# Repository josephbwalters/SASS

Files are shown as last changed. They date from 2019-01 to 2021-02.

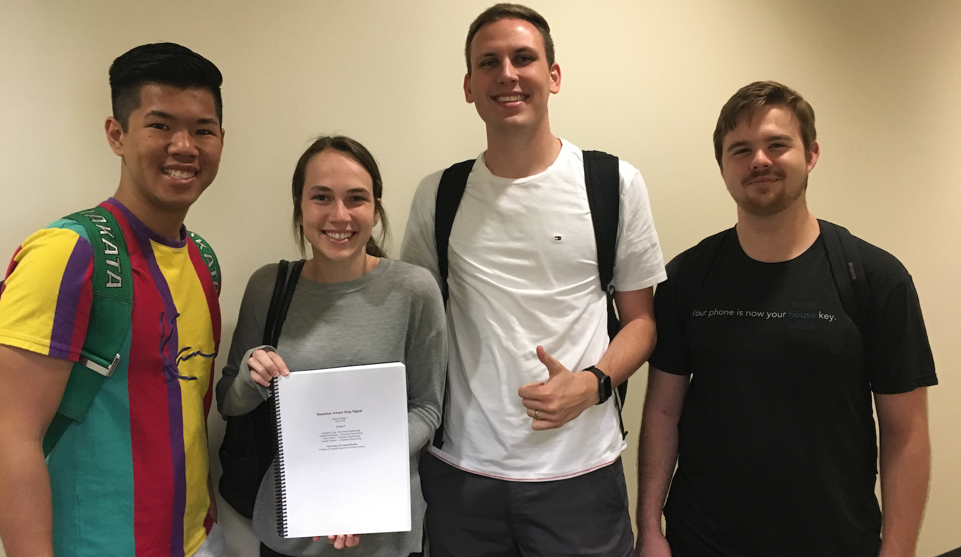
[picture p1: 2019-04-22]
docs/img/slider/SD1Paper_cropped.jpg

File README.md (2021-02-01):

# SASS
Repository for all code related to UCF CECS Senior Design Project (S.A.S.S. -- Fall 2018 - Spring 2019)

[SASS Github Pages](https://josephbwalters.github.io/SASS/) - Product overview and team details!  
[UCF SASS Website](https://www.ece.ucf.edu/seniordesign/fa2018sp2019/g03/) - it is a copy of our overview site  
[All UCF Projects](https://www.ece.ucf.edu/seniordesign/projects.php) - all UCF senior design projects  

## Installation:
- Clone Repo
- Open SASS, MSS, and DSS seperately in Code Composer Studio (CCS)

## Building Software
### SASS
- Build using CCS

### MMWAVE
- Build DSS in CCS
- Then build MSS in CCS

## Flashing Firmware onto devices
*Note: This is done after building each component*
### SASS
- Using CCS and a MSP432P401R EVM (Dev. Kit) you can flash the system externally

### MMWAVE
- Take the mmwave .bin file from the MSS' Debug folder and use UniFlash to flash the mmwave EVM

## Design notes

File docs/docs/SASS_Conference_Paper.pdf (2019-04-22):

# Situation-Aware Stop Signal

Jon Ling, Annabelle Phinney, Trent Sellers,

### Joseph Walters

Dept. of Electrical and Computer Engineering, University of Central Florida, Orlando, Florida, 32816-2362

Abstract — Advancements in technology made in the last two decades have made possible the rethinking and redefinition of traffic control at small intersections. Using new and more affordable LiDAR and RADAR technology, the Situation-Aware Stop Signal is aimed to reduce the number of accidents that occur on the smaller roads of our communities and, ultimately, save lives. A sustainable, solar-powered design allows the stop signal to be deployed and maintained for a low cost while eliminating its need for area utilities.
Index Terms — Embedded software, microcontrollers, millimeter wave radar, road transportation, solar energy, sustainable development, traffic control.
I. INTRODUCTION

At the crossroads of one small neighborhood in Orlando lies a small memorial at the corner of a four-way stop. It stands in remembrance of someone’s loved one – a neighbor – who lost their life in a fatal accident in that very same place. Every year, in our community and in others, there are a multitude of accidents that occur at small, residential intersections controlled by stop signs. A 2002 study by the Insurance Institute for Highway Safety found that one third of all intersection crashes in the United States, and over 40% of those fatal, took place at intersections where these were the primary traffic control device [1]. Accidents of this kind are often the result of drivers running stop signs due to visual distraction, the influence of alcohol, and other forms of carelessness. Stop signs have long been important tools for controlling traffic at small intersections, but they are becoming less effective in an age when both traffic and distractions are more present than ever on the road.
Since the first stop sign was installed in Detroit in the year 1915, the approach for managing traffic at small intersections has not changed by a great amount. The need for change, however, has never been greater. Living in an age dominated by small, bright screens and various forms of handheld or otherwise easily-accessible entertainment, there is more potential for accidents to occur today than in any other time in history. These new distractions introduce complex issues into the realm of roadway safety and pose a serious threat to drivers if not mitigated.
A concern for the safety of others, paired with an admiration of current technology, has led us to rethink traffic control at the enforced stops of our community. The culmination of this thought is the Situation-Aware Stop Signal. Where conventional stop signs are insufficient, the Situation-Aware Stop Signal is intended to draw greater attention to the roadway and be a catalyst for safer crossings at small intersections. Influenced by technology found in existing traffic lights and autonomous cars, this intelligent system is designed to be a modern and more effective replacement for the stop sign. Using advanced sensors and real-time computing, the Situation-Aware Stop Signal is able to monitor the intersection for traffic and provide intuitive warnings to drivers.

II. OBJECTIVES

A. Prevention of Threat

A threat exists when a driver does not slow down as he or she approaches the intersection. This may be due to some form of a distraction, such as the use of smartphones while driving, or could be the result of driving under the influence of alcohol or other impairing drugs. For this situation, the stop signal was designed to alert the driver to slow down and to come to a complete and safe stop.
By triggering the driver’s senses, particularly sight, the stop signal is able to help him or her maintain his or her eyes on the road ahead. Implementing this required a need to understand human psychology and the behavior people tend to exhibit while driving. Throughout our study, we observed that people seem to respect traffic lights more than stop signs. This observation was fundamental in exploring our method of redirecting the driver’s attention.
To capture attention and prevent a driver from driving through the intersection, the stop signal indeed acts similar to existing traffic lights. Until a vehicle comes to complete stop, the signal provides a solid red light as an indicator that the driver must stop. This was decided due to people’s familiarity with the stops of larger traffic control systems and their association of these with the consequences of violating such stops. When a vehicle has remained stationary for a period of time at the stop bar, the signal gives a flashing yellow light to indicate that the driver may proceed with caution. It was decided against using a green light to 1) invite the driver to be aware of other vehicles even while crossing and 2) provide a distinguishable experience from that of larger traffic control systems.
B. Protection from Threat
v = $2 ∗ range ∗ μ ∗ g | (1)

Should a driver constitute a threat and not slow down as he or she is entering the intersection, it is of critical importance to alert all other drivers at the intersection and keep them immobilized until the threat has passed. In such a situation, the traffic control system must attempt to keep everyone safe. This situation is given the highest priority amongst all other situations that may occur at the intersection.
A threat must be detected and classified well before it reaches the intersection. Here, a study of car velocity, driver reaction time, and safe stopping distance was required to properly identify danger. These factors were considered in the interpretation of sensor data and the primary function of the algorithms that were written in the project software. This ability to process data was directly dependent on the speed at which it could be captured. This second consideration, a need for real-time situational awareness, was the principal consideration of the embedded software design.
The Situation-Aware Stop Signal uses mmWave RADAR to track vehicles as they approach the intersection. As RADAR tracks a vehicle, it continuously compares its speed to that which it considers safe given its distance from the intersection. This analysis is represented in (1). Once RADAR detects a threat, the system immediately enters an emergency mode. In this mode, all lights are turned red, preventing any other vehicles stopped at or approaching the intersection from crossing. The stop signal continuously checks all sides until no threat remains. Once the intersection is determined to be safe, the signal exits the emergency mode and resumes normal operation.
C. Scheduling of Traffic

Oftentimes, drivers stop at the intersection at the same time and do not proceed for concern of incorrectly assuming or yielding the right of way. When this occurs, not only is traffic flow constrained, but a new threat to safety may be presented. By implementing basic scheduling with the stop signal, we took an opportunity to correct this issue.
We acknowledged current traffic laws and designed our system to direct traffic in a manner that is consistent with the behavior they dictate. We aimed to recognize all combinations of driver presence at the intersection and understand the order by which traffic should proceed in every unique case. A study of driver behavior and arrival times at small intersections was necessary to sufficiently consider timing when scheduling traffic. Although this was likely to vary greatly between drivers and locations, an average or more probable pattern of traffic flow and management was defined.
To implement fair scheduling of vehicles at the intersection, we designed the stop signal to operate using a simple FIFO queue. Simply put, the first vehicle to arrive is the first vehicle to be scheduled. The management of this queue performed by software running on a 48MHz processor allows the stop signal to capture vehicles when they arrive – whether they be hours, minutes, seconds, or microseconds apart. Current traffic laws indicate that should two vehicles arrive at the same, the one on the left should yield to the one on the right. With the Situation-Aware Stop Signal, virtually no vehicles are found to arrive at the very same time. There is always a “winner”: the one who is found to arrive first.

III. SELF-SUSTAINABILITY

The Situation-Aware Stop Signal was designed to be self-sustaining. Although its manufacturing cost was acknowledged to be greater than conventional stop signs, it was determined that it should not imply a significant operational cost. Current traffic control systems at larger intersections require connections to area utilities and are either dependent on existing infrastructure or demand its extension. Such investment and continuing operational costs can lead to a great expense for the governments or private industries that manage them. Contrarily, the stop signal was created to reduce these costs and be deployable in diverse locations where area utilities may not reach.
To be independent of local power grids, the stop signal operates on solar power. A 28-inch by 28-inch solar panel rests overhead of the main control box and generates over 80W of power using 25 solar cells at 0.6V at 6A each. These solar cells were produced by Sunpower, which are currently the industry leader for consumer level solar cell production. These cells are a monocrystalline design which means that it is pure slices of silicon rather than melting smaller pieces of silicon into a single cell. Because these cells have less imperfections than its competitors, it allows them to be more efficient.
A solar charge controller manages power generated by the solar panel and regulates its storage in an on-board 12V lithium ion battery. While the solar panel is producing more than the device’s operating voltage, the charge controller will regulate the voltage going into the device to the desired 12V. To optimize the storage of the power generated via the solar panel, a MPPT (maximum power point tracking)

charge controller was used. The MPPT charge controller similar technology as PWM (pulse width modulation) charge controller; however, these charger controllers can retain more of the generated power. With other PWM charge controllers as well as single stage charge controllers, excess voltage will be lost upon supply to the battery. With an MPPT charge controller, excess voltage can be converted into additional current. Using MPPT charge controllers will allow for larger solar panels which may be to maximize usable solar panel space.
By providing over 80 watts to our battery while only consuming about 12, our device stays low power. The additional power consumed during sunshine hours will be used to charge the battery. Florida produces about six solar hours a day, so the solar panel needed to produce at least four times the devices demand to say sustainable. This would account for the continuous operation of running 24 hours in a day. The battery that was chosen for this project has a capacity of 20Ah. Given our design operates at under 1A draw, our device will be able to operate for a day without any sunlight hours. Having the battery backup allows for days that have small amount of sun hours.

IV. MODULARITY

Modularity is vital to provide easy means of adjusting the signal to meet the needs of any intersection. While the goal of this project was to design a signal intended to replace stop signs at smaller intersections, the product was designed modularly with the ability to be expanded to larger roadways and eventually be used to replace traffic lights. Modularity appears throughout the device; where there is hardware modularity, there is also software modularity that conveys the design’s robustness.
The physical design is where most of the modularity is seen. The use of 3D printed mounting brackets for both the RADAR and LiDAR sensors, allows the user to adjust the angle of the sensor to meet the needs of any intersection.** Additionally, with so many different types of intersections out there, the addition of removable side modules allows the user to add to take off any of the sides to suit the intersection more accurately. While our design only has two side modules on currently, more modules can easily be added in the future thanks to the use of the connectors on the back of the center module. As mentioned previously, testing the device with ease was another aspect in our design. Accessing the hardware inside each module was necessary to debug and ensure that all the components of the design were working together correctly. This was achieved by adding sliding hinges to the modules. This allows the owner to see the inside of the module and spot issues more easily. These additions to the physical design improved the quality of testing and highlight the easily adjustable nature of this unique stop signal.
Modularity also exists in the software. With the ability to add or remove more sides to the signal, comes the ability to adjust the software to the size of the current intersection. With just a simple numerical entry of the number of required sides, the software can detect cars from as many sides as the user requires and pull from the appropriate number of sensors. This can help improve efficiency and save power. If some users only require one modular side, the sensors in the remaining sides will be off and not be collecting unnecessary data, thus improving efficiency. Additionally, an ample amount of power is saved by not turning on extra lights and sensors.
Power is the final aspect of the modularity in this design. Because a requirement of this device was self-sustainability, the main source of power for this project is the solar panel. While this may provide the required amount of power, the majority of the time, when there is little to no natural sunlight, the device still needs to be functional. To achieve this, the addition of the battery introduces an additional power source for the device. While the sun is out, the device can be directly powered from the solar panel, however, on a cloudy day, the power gathered from the panel which is stored in the battery can be used to keep the signal functional. This second power source creates additional modularity for the system to ensure this device will be constantly operational.

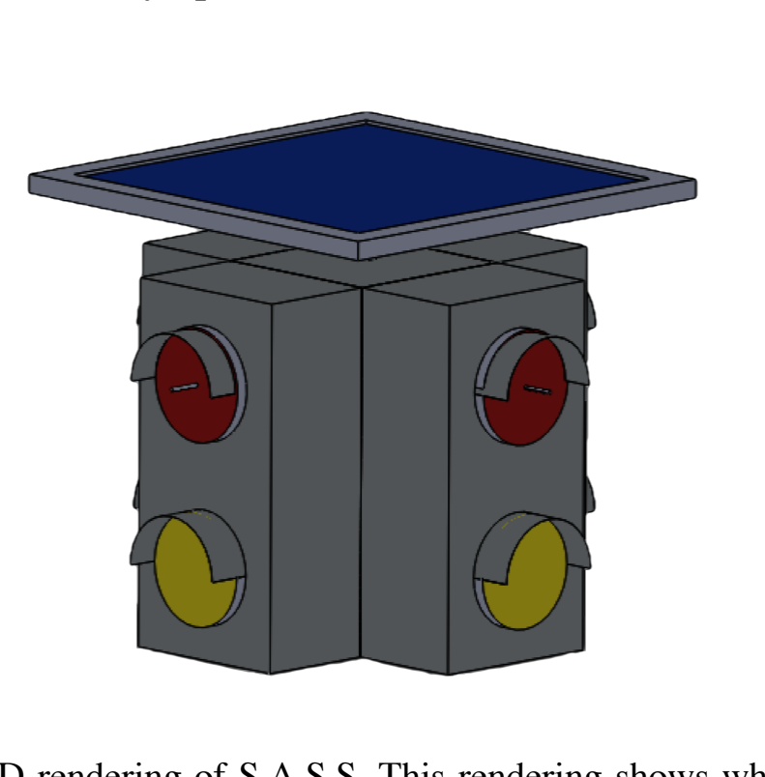
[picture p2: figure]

Fig. 1. 3D rendering of S.A.S.S. This rendering shows what the device would look like if implemented for a 4-way intersection.

V. STANDARDS
The design goal of this device was to mimic the look of a current stoplight that is seen on an everyday intersection. For this reason, we closely followed the Manual for Uniform Traffic Control Devices. All box dimensions, light sizes, and height have been in accordance with the Department of Transportation’s standards.
Indicated in Figure 4D-4 in the Manual for Uniform Traffic Control Devices, the standard for the 12-inch lights presents a maximum of 180 feet from stop line to signal face. The standard for 8-inch signal indications is 120 feet from signal face to stop line.
The Manual on Uniform Traffic Control Devices states that traffic signals should determine who has the right of way by using priority control. Priority control is used by the signal to select the driver with the right of way by allowing whichever driver who stopped at the intersection first, to proceed through the signal first.
In addition to the traffic standards that were followed when creating this project, there were many hardware standards and testing standards that allowed the project to be completed correctly. While we are only dealing with low power electronics, it is still vital that the power supply and delivery standards be followed correctly. These efficiency standards for power supplies provide tests for the worstcase scenario of the circuit and require certain minimum and maximum power outputs in any scenario.

VI. HARDWARE
The one major focus of the hardware design was to save power. This engineering requirement played an important role in both choosing hardware, such as sensors as well as how designing the PCB. Another goal of the hardware was to create redundancy and ensure the safety of all drivers. To achieve this, two different types of sensors were included in the stop signal: RADAR and LiDAR. These sensors, along with the PCB makeup the hardware electronics. The PCB was able to be designed without a maximum size requirement while keeping in mind an efficient output. Because this system will operate in real time and need to rapidly control lights, minimizing unnecessary components and trace lengths helped improve the functionality. Additionally, because the device will be operating outside, eliminating excess heat was achieved by swapping out a large linear regulator with a switching regulator. While the linear regulator helps eliminate noise, it loses a lot of power through heat dissipation. Because this board does not contain any major high frequency elements, saving power was more important than eliminating noise, which is why the switching regulator was used for the 12V to 5V step down. While power efficiency was a large concern, testing was another one. As a result, the PCB was designed with testing in mind. Signal LEDs and test pins were incorporated throughout the PCB to ensure that the regulators and other major components could easily be tested. This helped to easily identify and correct any major issues with the PCB.

At the heart of the PCB is the TI MSP432P401R microcontroller. Not only do we need a design that is power efficient, we need a design that can also perform adequately to read and interpret sensor data provided by the RADAR and LiDAR modules. This processor was chosen due to its extra memory, large number of GPIO pins, and compatibility with RTOS. This MCU also provided a quick and efficient means of flashing code, testing, and debugging the software. Because the MSP432P401R evaluation board was provided to us by the TI lab for testing the MCU, we were able to also use this evaluation board to flash our board with the designed software. This made testing both easy and efficient.
Accuracy was another major requirement of this project. In order to monitor and control traffic, creating redundancy allowed for us to ensure the safety of drivers who cross the intersection. This redundancy was achieved by sensor fusion or the use of both RADAR and LiDAR sensors to detect oncoming traffic. While the LiDAR and RADAR are being used in different ways to detect traffic, together they will provide more accurate readings of the way that traffic is behaving.
The RADAR module chosen uses mmWave sensors to detect objects with a frequency of over 100 GHz, the smaller wave size provides a more accurate and speedy result when detecting objects. This module includes an evaluation board that helps process the data gathered from the RADAR. As a result, this module will be placed inside the signal. The focus of the RADAR board is to gather the position and velocity of all oncoming cars. It will also detect and alert our PCB of any potential threats to the intersection.
Like the RADAR, the LiDAR is a time of flight sensor that uses a laser to detect objects within a thin beam width. While the LiDAR does not include an evaluation module, it includes a durable weather resistant casing, which allows the sensor to be placed outside the module. The main job of this LiDAR module is to initially detect any car approaching the signal. This sensor will be alerting the PCB if an object is detected and stopped at the stop signal. Then, unless a threat is detected by the RADAR, the LiDAR will alert the PCB that there is an object and, after the appropriate amount of time, allow that car to proceed through the intersection safely. The use of two different types of sensors that cover different ranges allows for more data and the redundancy required to provide a safe means of controlling traffic.
In addition to the hardware electronics, comes the power hardware. In order to make our device both power and cost efficient, a solar panel was chosen to be the main source of power for this device. This decision was made not only to save the user the cost of tying this device to the power grid, but also to increase ease of installation. While some components of this device are relatively more expensive than the traffic lights, the total cost saved from using solar power versus grid power makes up for the more expensive sensors used in the project. Also, the use of the solar panel can reduce the installation time drastically and allow this device can placed nearly anywhere, regardless of whether there are power lines near or not.
Because the solar panel was designed and created by us, we were able to focus on purchasing the most efficient solar cells possible to improve the overall power gathered from the panel. For example, since monocrystalline solar cells can generally produce more power than polycrystalline cells, these were chosen for the solar panel. While these cells were a bit more costly, it was worth the additional power gained to use them. Also, building a solar panel allowed for additional savings.
While the solar panel provides a lot of power, there is still a need to power the device in overcast or cloudy conditions. To do this successfully, a battery was chosen as an additional power source to allow the device to still work when there is not enough sunlight to power the solar panel. The battery chosen to do the job was the GTK 3S Lithium Ion battery. These batteries store more power and charge faster than lead acid batteries. The battery chosen was also much lighter than alternatives. This helped lower the overall weight of the traffic signal.
To ensure reliability and efficiency of the design, an MPPT charge controller was added to supply a constant voltage from the battery even while to device is charging. We decided to use an MPPT style charge controller over a PWM charge controller. MPPT charge controllers offer efficiencies over 95%, and the one we decided on has a max efficiency of 98%. By utilizing a charge controller, the lifespan of the battery can be improved. Charge controllers improve the lifespan of the battery by trickle charging after the battery is nearing maximum capacity as well as providing protection against overcharging. The charge controller will be placed between the battery, solar panel, and PCB. For our application, our solar panel will produce 15 volts during operation. Our charge controller is rated to be able to step this down to 12 volts during operation which is a key feature of this device. The charge controller also includes a display that will show the status of both the battery and charge controller. With the addition of the charge controller, the voltage that the PCB receives can now be limited and regulated to a near constant value.

VII. SOFTWARE

The software of the system is broken down into four components which are:

1) Low-Level Hardware Abstraction
2) Object Detection
3) Object Classification
4) Traffic and Light Control

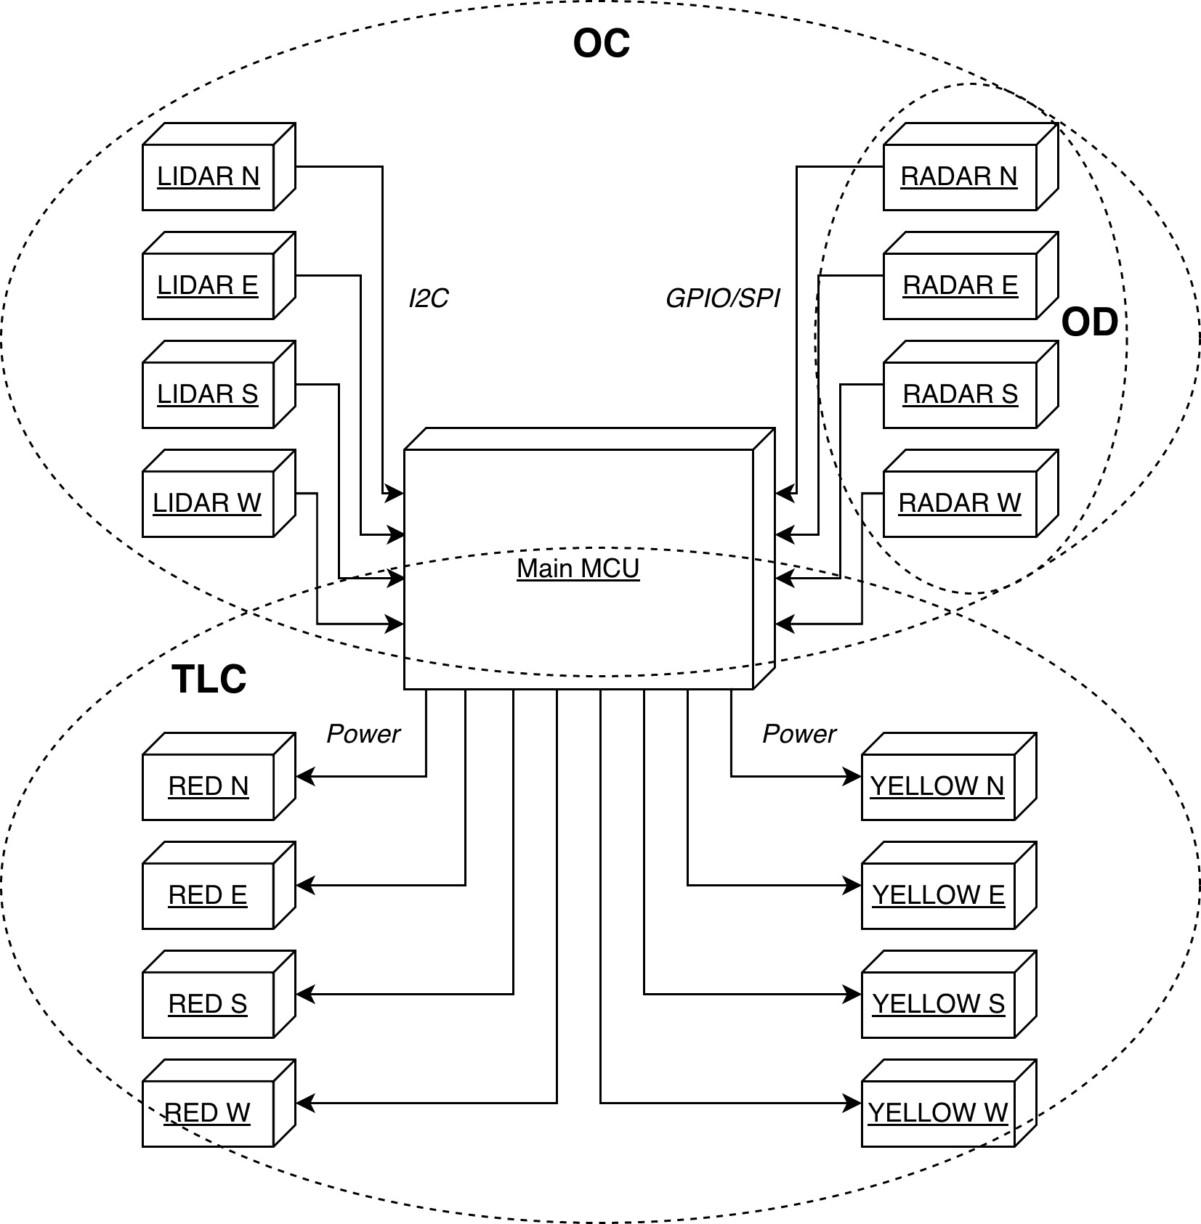
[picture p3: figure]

Fig. 2. Deployment diagram depicting three of the four software components used in the Situation-Aware Stop Signal: Object Detection (OD), Object Classification (OC), and Traffic and Light Control (TLC).
A. Low-Level Hardware Abstraction (LLHA)

The LLHA component is responsible for abstracting out the hardware that we used to prototype the design. Since we want this system to be modular and adaptable, it was essential that we design a common API-based system to perform all of the hardware-based functionality of our system. Doing this also simplified the design of the higherlevel logic that we were to use in the rest of the system. Currently, the LLHA component controls the lower-level settings for the LED lights, the I2C communication for the LiDAR, and the SPI communication for the mmWave device. This is done so that we can abstract out the hardware required for each side of the device in a modular way. The device could theoretically have 4 sides, so the software is designed to accommodate those sides through the settings within the LLHA submodule.

B. Object Detection (OD)

The OD component is responsible for detecting objects that the system can then respond to. This module relies on both the mmWave RADAR sensor and the LIDAR-Lite v3HP LiDAR sensor to detect vehicles that are entering the intersection. Object detection mainly takes place on the mmWave device since it is more capable of sensing vehicles that are moving towards the intersection. Then, once the vehicles are approaching the stop bar, the LiDAR device takes over and provides added information as to when the vehicle stops at its specified location.

C. Object Classification (OC)

The OC component isresponsible for determining if each oncoming vehicle is considered safe or unsafe based on (1). Similar to the OD module, OC is started on the mmWave device which monitors the oncoming vehicle to constantly check if the vehicle is safe or not. Once a vehicle is determined unsafe, the mmWave device then triggers a hardware interrupt that will then force the system into emergency mode.
Alternatively, if the vehicle is determined to be safe then the system will operate normally, resulting in the device monitoring the LiDAR sensor for a vehicle that stops at the specified location for that side of the intersection.
Once the vehicle is in the proper location, the OC module is responsible for verifying that the vehicle is also still located in the intersection at that location. After validating that information, then the OC sends the vehicle object to the queue managed by the TLC submodule.

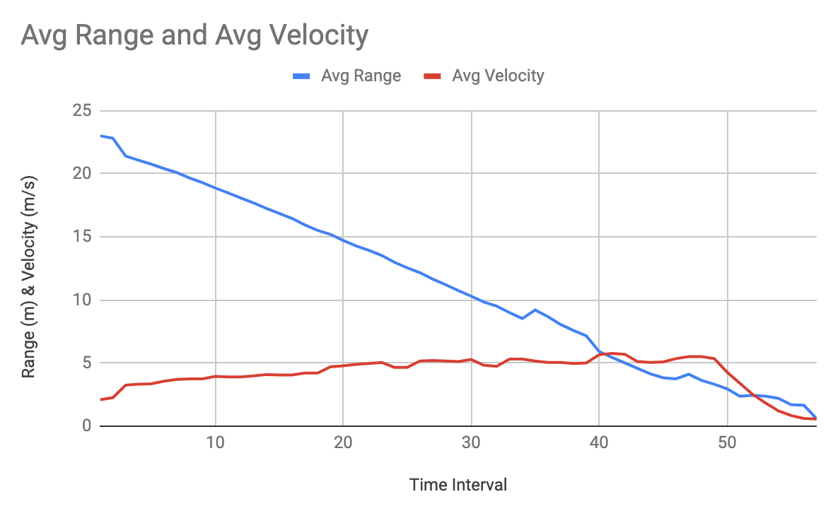
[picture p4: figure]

Fig. 3. Noise-reduced model of time vs range and velocity data gathered by the mmWave RADAR sensor (from captured logs).
D. Traffic and Light Control (TLC)

The TLC component is responsible for monitoring the state of the device and scheduling vehicles as they arrive in the intersection. This is achieved by inserting a new vehicle object into a queue. Doing this allows us to monitor each vehicle that arrives in the intersection while also keeping track of which side the vehicle has approached from. By doing this, we allow the TLC submodule to understand the state of the entire system, without knowing the implementation of the rest of the system. This is perfect for a traffic control device like this as it allows the scheduling mechanism to be updated and changed independently of the rest of the system and could then be optimized to allow for higher throughput.
The TLC is the perceived heart of the system as it is the only module that directly affects the external world. If the TLC does not work, then the entire system is a failure since it is the management system for all of the lights and traffic control. Currently, the TLC and the rest of our system abide by all of the standards and regulations defined in the Manual on Uniform Traffic Control Devices (MUTCD) and, accordingly, the system has a failsafe mode so that the system can deal with software and hardware failures as necessary.
E. Emergency Mode

As briefly noted, on detection of an unsafe vehicle, we trigger a hardware interrupt to force the system into an emergency state. We decided to use an interrupt-based approach because this would ensure that our system responds to the thread regardless of the thread that is currently running.
While in emergency mode, we rely on the mmWave sensor on each side to report back through the GPIO pin the status of the vehicles that are in view. While checking the status of each vehicle, we keep all lights on the system set to red to indicate that no vehicle is allowed to enter the intersection as there is a possible threat. Based on our implementation, as long as there is a vehicle that is detected that is considered a threat, the system will stay in this mode.
F. Failure Mode

Since drivers rely on traffic control devices to determine their actions when driving, it is important to ensure that our system is reliable and safe. Because of this, we included a default error-catching utility using a software interrupt that forces the system into a permanent failure state until the system is reset. In this mode, the system follows common traffic laws outlined in the Manual on Uniform Traffic Control Devices and the system will blink red approximately sixty times per minute to ensure that operation of the intersection defaults to that of a typical 4-way stop. Errors that could cause this are deadline failures, LiDAR sensor failures, and control failures. This ultimately gives the system a reliable way to fail without causing any sort of accident.
Since the software interrupt handles the LiDAR sensor failures, we still need another way to handle the mmWave sensor failures in case that sensor fails. If the sensor were to fail, it would never trigger that interrupt and in this case, that results in normal operation for the device, without the emergency detection feature.
For a more robust approach, this interrupt driven approach could be adapted to include more features such as self-reset and/or external LTE communication out to let a central control center know that the system is down. For us this was not within scope of the project in the time frame that we have, but it would be something that is important for a real production level system that is within the intersection.
G. Real-Time Operation using TI-RTOS

It was determined early on in the design of the Situation-Aware Stop Signal that the system should operate quickly, reliably, and deterministically due to its safety-critical nature. For this reason, it was decided that the software should be managed by a real-time operating system (RTOS). TI-RTOS, Texas Instruments’ own RTOS product, was selected as the operating system to power the stop signal software because of its open-source nature and extensive support for both the MSP432 microcontroller and C++ programming language.
Multithreading support in TI-RTOS allows the stop signal software to run multiple threads of execution. Because the MSP432 microcontroller has one core, these threads are scheduled so execution time is shared in a fair and deterministic manner. The Situation-Aware Stop Signal software makes use of priority scheduling and three unique types of threads provided by TI-RTOS: tasks, software interrupts (SWI), and hardware interrupts (HWI). SWI inherently have greater priority than tasks, and HWI greater priority than SWI. Tasks are used for code pertaining to regular, safe operation. SWI are used to trigger system failure should any hardware or software issues exist. HWI are used to trigger the emergency mode when a threat is detected, exhibiting the highest priority to ensure the safety of drivers at the intersection.

VIII. FUTURE USE

Currently, the Situation-Aware Stop Signal is designed for an intersection with stop signs, but that does not mean that this technology or our methods are not adaptable to more complex intersections. With RADAR and LiDAR technologies becoming more affordable within the last decade and advancements in low-power computer visionbased systems, it is much more likely that traffic systems will start being updated to do exactly what we have done with small intersections.
Computer vision is typically expensive and powerhungry but with new systems like the Nvidia Jetson and mmWave Radar sensor it is possible to replace the timerand induction-based systems with RADAR, LiDAR, and computer vision systems. Doing this is currently not costefficient, but over the next few years it could be within reach to start replacing those systems to include smarter technologies to detect threats, increase throughput, decrease waiting time, and catch criminals.
One additional and needed feature for updated systems like S.A.S.S. would be an ability to catch and ticket drivers for not abiding by the laws of the road. This is because this is a large source of income for the states. Many systems do this already, but this would enhance that functionality and also bring it to smaller intersections that are more likely to have accidents.
Another possible use case for systems like this is exactly the use case that we addressed with S.A.S.S. We currently solved the problem for small intersections, but with more time, money, and equipment it is completely possible to increase the efficiency of the software and to enhance its functionality by allowing the system to monitor larger areas and accommodate different types of detected objects such as pedestrians, bicyclists, and animals. Doing this would allow a traffic management system to monitor the safety of drivers and pedestrians in a proper manner and could easily prevent accidents in high-traffic, inner-city roads.
With that in place, it is also possible to increase throughput of all vehicle and pedestrian traffic by allowing the system to control each component of the system and determine the optimum timings to allow for maximum throughput using machine learning. Some systems already do this using computer vision and sensors within the roadways, but this could give a more robust solution that relies less on sensors embedded in roadways.
While the device is already somewhat modular, in the future, even more modularity could be incorporated in the signal. While the device can detect bicyclists, a crosswalk or pedestrian crossing is very common in most intersections. The ability to detect pedestrians and alert the drivers by turning all the lights red could improve upon the goal of saving people’s lives. While we originally wanted to be able to mount the solar panel on top of the device and have the ability to be rotated depending on the sunlight. A rotating solar panel would increase the amount of sunlight the solar panel could use and, as a result, provide more power to the device in a shorter time. With more money, resources, and time, a movable solar panel bracket could greatly improve the self-sustainability aspect of this device. Also, because the device itself required more power than originally expected, in the future, a larger battery with more capacity would be used to reach the goal of being selfsustainable for two days without sunlight. Because there is still a lot more space in the device, a larger battery would not affect the physical design.

IX. CONCLUSION

The Situation-Aware Stop Signal demonstrates the effectiveness of modern technology working in concurrence with outdated traffic units. While following MUTCD traffic laws, this device built upon current traffic control units which relied on timed algorithms. Using LiDAR and RADAR sensors, this device is able to detect where cars are within an intersection and use this data to more safely and effectively control traffic.
A major requirement of the Situation-Aware Stop Signal is to keep drivers safe and prevent car accidents. With this in mind, the design challenge became how to orient this device so that it does not distract or confuse drivers. The solution to this challenge was to design the device so it resembled a traffic light, the difference being that our device does not have a green light. This decision was made as a result of our implementation directed towards smaller intersections. Rather than giving the drivers the “go” signal, this device tells drivers to “proceed with caution.” Proceed with caution better fit the scenario for the traffic device which was being replaced.
While the idea is expandable to larger intersections, the goal of this project was to focus on smaller intersections that currently have stop signs. Technology such as robust as RADAR and LiDAR are scalable to larger applications. Applying this idea to larger areas could reduce the amount of traffic incidents, increase the flow of traffic in dynamically changing traffic patterns, and provide lower cost traffic control to modern, adapting areas.
Ultimately, the Situation-Aware Stop Signal will be selfsufficient and able to easily be integrated into society because of its stop-light-like appearance. We hope this project improves traffic on low volume roads while reducing both traffic accidents and waiting time for cars. This idea opens up further opportunities to expand and build upon the idea of a smart, intuitive traffic signal.

ACKNOWLEDGEMENT

The authors would like to acknowledge Texas Instruments for providing them with two of their latest IWR1642 mmWave RADAR sensor evaluation modules, two MSP432P401R evaluation modules, and various samples for other processors, regulators, and other minor components for free. They thank Don Harper and the staff of the TI Lab for allowing them to use their equipment to fabricate the physical components of our device.
They also want to express their appreciation for the mentoring, support, and feedback of Professor Michael

McAlpin during the development of the Situation-Aware Stop Signal.
Finally, the authors wish to acknowledge the families of those individuals who have lost their lives in motor vehicle accidents at small intersections and at all crossroads of their communities.

AUTHORS

Jon Ling is an electrical engineer from Merritt Island, Florida. Jon worked primarily on the power system, mechanical design, and PCB of the Situation-Aware Stop Signal, focusing on the distribution of power from the solar panel and battery source to all electrical components in the system.

Annabelle Phinney is an electrical engineer from Jupiter, Florida. Annabelle worked primarily on designing the PCB of the Situation-Aware Stop Signal, architecting much of the printed-circuit design while researching and acquiring the necessary electrical components.

Trent Sellers is a computer engineer from Orlando, Florida. Trent worked primarily on the embedded software of the Situation-Aware Stop Signal, focusing on the programming of the PCB
with | a | particular | emphasis | on
multithreading | and | real-time
applications.

Joseph Walters is a computer engineer from Orlando, Florida. Joseph worked primarily on the embedded software of the Situation-Aware Stop Signal, focusing on the programming of the TI mmWave RADAR module with a particular emphasis on algorithm development and communications.

REFERENCES

[1] “Drivers Often Stop but Don't See.” IIHS, 2002, www.iihs.org/iihs/sr/statusreport/article/37/9

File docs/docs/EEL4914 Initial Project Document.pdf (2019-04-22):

Initial Project Document

## Situation-Aware Stop Signal

Senior Design 1

Group 3

Jon Ling - Electrical Engineering Annabelle Phinney - Electrical Engineering Trent Sellers - Computer Engineering Joseph Walters - Computer Engineering

University of Central Florida College of Engineering and Computer Science

Group 3
EEL 4914
09/27/2018

Project Narrative

At the crossroads of one small neighborhood in Orlando lies a small memorial at the corner of a four-way stop. It stands in remembrance of someone’s loved one – a neighbor – who lost their life in a fatal accident in that very same place. Every year, in our community and in others, there are a multitude of accidents that occur at small, residential intersections. These are often the result of drivers running stop signs due to visual distraction, the influence of alcohol, and other forms of carelessness. Stop signs have long been important tools for controlling traffic at small intersections, but they are becoming less effective in an age when both traffic and distractions are more present than ever on the road.

Our goal is to design a system that has the potential to change our community – that is, to improve driver safety and save lives. We propose a replacement to the conventional “stop sign.” We propose a Situation-Aware Stop Signal.

The Situation-Aware Stop Signal, influenced by technology used in existing traffic lights and autonomous cars, is designed to be modular and implementable at small intersections currently guarded by stop signs. Using object-detecting technology like RADAR and LIDAR, the Situation-Aware Stop Signal is capable of detecting approaching vehicles and intelligently alerting drivers. Situational awareness made possible by its strategic placement allows the Situation-Aware Stop Signal to anticipate safety-critical events before they occur.

This ability is conducive to a two-part mission for the project:

1. To help drivers stop safely before the intersection
2. To protect drivers from others who may not be stopping safely at the intersection

To help a driver stop safely before the intersection, a traffic signal is displayed to alert the driver that he or she is nearing the intersection and needs to stop. To protect a driver from others who may not be stopping safely at the intersection, the driver is given a visual alert if cross traffic is detected as coming from either perpendicular direction. This is particularly useful for intersections that are populated with trees and other objects that may obstruct the driver’s vision when preparing to cross the roadway.

09/27/2018

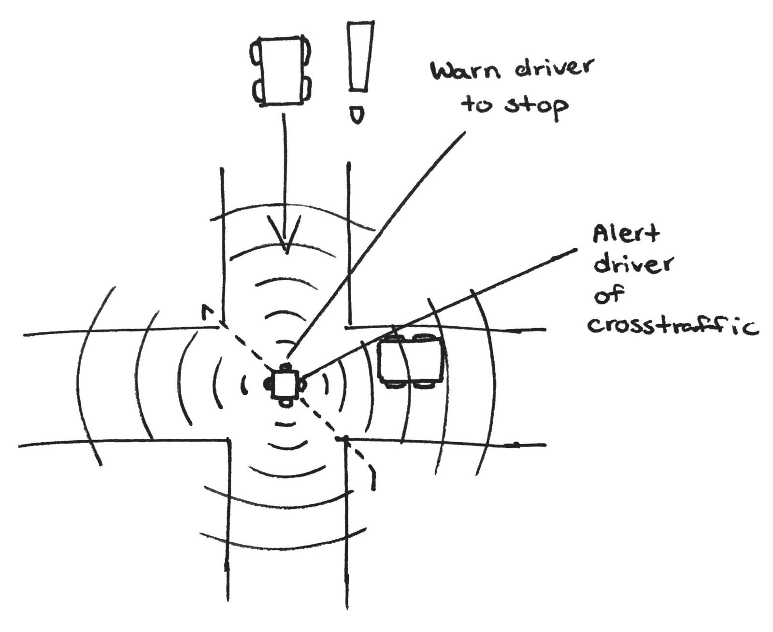
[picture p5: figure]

Figure 1: Sketch of idea

In order to achieve this ambitious mission, it is necessary for the product to be accurate as well as self-sustaining. To make itself a candidate for real-world application, the Situation-Aware Stop Signal is designed to use solar power as its primary source of energy. By emphasizing sustainability and low-cost components, we intend to make a device that is appealing to companies and governments as an affordable solution for both private and public roadways.

Currently, the market targeted by this product is dominated by the very low-cost stop sign. Although it brings with it a low price, the stop sign is a primitive product that has changed very little in the last 100 years. With the advances of today’s technology, we believe that we can design an affordable alternative with the features needed to ensure a safer community.

Ultimately, it is a safer tomorrow that we hope this inspires. In an age when technology has made its way into some of the most trivial parts of our lives, infinite remain the opportunities to use it in everyday, untouched places with tremendous impacts – especially in those where it has not been widely utilized because of factors like cost and scale. In a day like today, where we go and how we safely get there may be ever-changing as technology becomes more affordable and more compact. This is the platform for the Situation-Aware Stop Signal.

09/27/2018

Requirements Specifications Product Features

High Priority Functionality:
- The device shall be modular so that it can be placed in whatever orientation is preferable to the user installing the signal
- The device shall signal drivers to stop or yield as needed
- The system shall warn drivers and pedestrians when there is cross traffic present
- The system shall control traffic at intersections to increase traffic flow rates Low Priority Functionality:
- The system shall have manual control for authorized personnel to control traffic
- The device shall take photos of vehicles that do not stop at the sign
- The device shall display the vehicle’s speed
- The system shall display a warning if the vehicles speed is deemed dangerous

Power Supply & Consumption

- System should be supplied by two sources for sustainability
- Solar panel located on/near the device
- Internal battery
- Backup battery
- Internal battery should be charged by the solar panel during the day
- Internal battery should last 12 hours or overnight
- When idle the system should go into low-power mode

Operable Conditions

- Weather resistant so that the system can last in normal outside conditions (IP52)
- Should remain operable between 20℉ and 200℉ (subject to change)

Safety Features

- Lights will warn vehicles but not be distracting enough to cause drivers to cause drivers to take their attention away from the road
- Signals will adhere to Florida road laws and suggestions
- Signals will be visible during the day and night
- In case of software failure or low battery (< 5%) the system should function as a simple stop signal

Accuracy & Tolerances

- Vehicles should be in view of our system between 1m and 50m
- All readings from sensors should be within +/- 5% from their actual value
- Completely false readings outside of that range should occur less than 5% of the time
- Internal battery should always remain in operable condition >2% battery level
- The system should respond to stimulus within 75ms

09/27/2018

Constraints

Our project has a few constraints imposed on it, the most important being the laws dictated by the US Department of Transportation which deal with how road signs may be displayed and used in accordance to local and state road laws. Other constraints imposed on our system include budget and processing power. This is reinforced by our need to have high quality sensors as people's lives are at risk and the system needs to be accurate, yet cheap to stay appealing.

The last constraint on our system is size: the product needs to be large enough so that we can mount a solar panel that can produce the correct amount of power to the battery for adequate charging and long term use. Yet, the product can’t be so large that it is difficult to move around or that it fails when windy conditions are introduced.

09/27/2018

House Of Quality

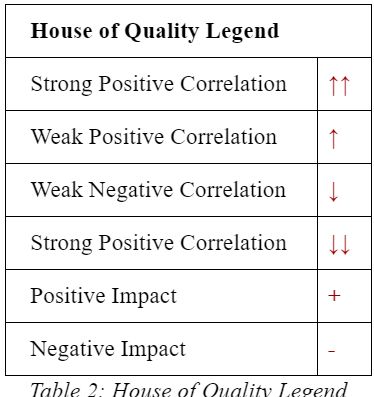
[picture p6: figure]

Marketing Requirement | | + | + | + | + | + | +
Regulate Traffic | + | ↑↑ | | | ↑
Self Sustained | + | | ↑ | ↑↑ | ↓ | ↓
Accuracy | + | ↑ | ↓ | | ↑↑ | ↓ | ↓
Low Cost | + | | ↑ | ↓ | ↓ | ↑↑ | ↓
Easy Installation | + | | | | ↓ | ↓ | ↑↑
Efficient | + | | ↑ | ↑ | ↓ | ↓
Engineering Requirement Targets | | Follows MUTCD standards of DOT Traffic Law (ie presentation placement ) | Needs < 20 Watts | Able to store 0.3 Wh per minute | 90% Accurate within 25 feet | < $215 | Installati on ~15 minutes

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
09/27/2018

Block Diagrams

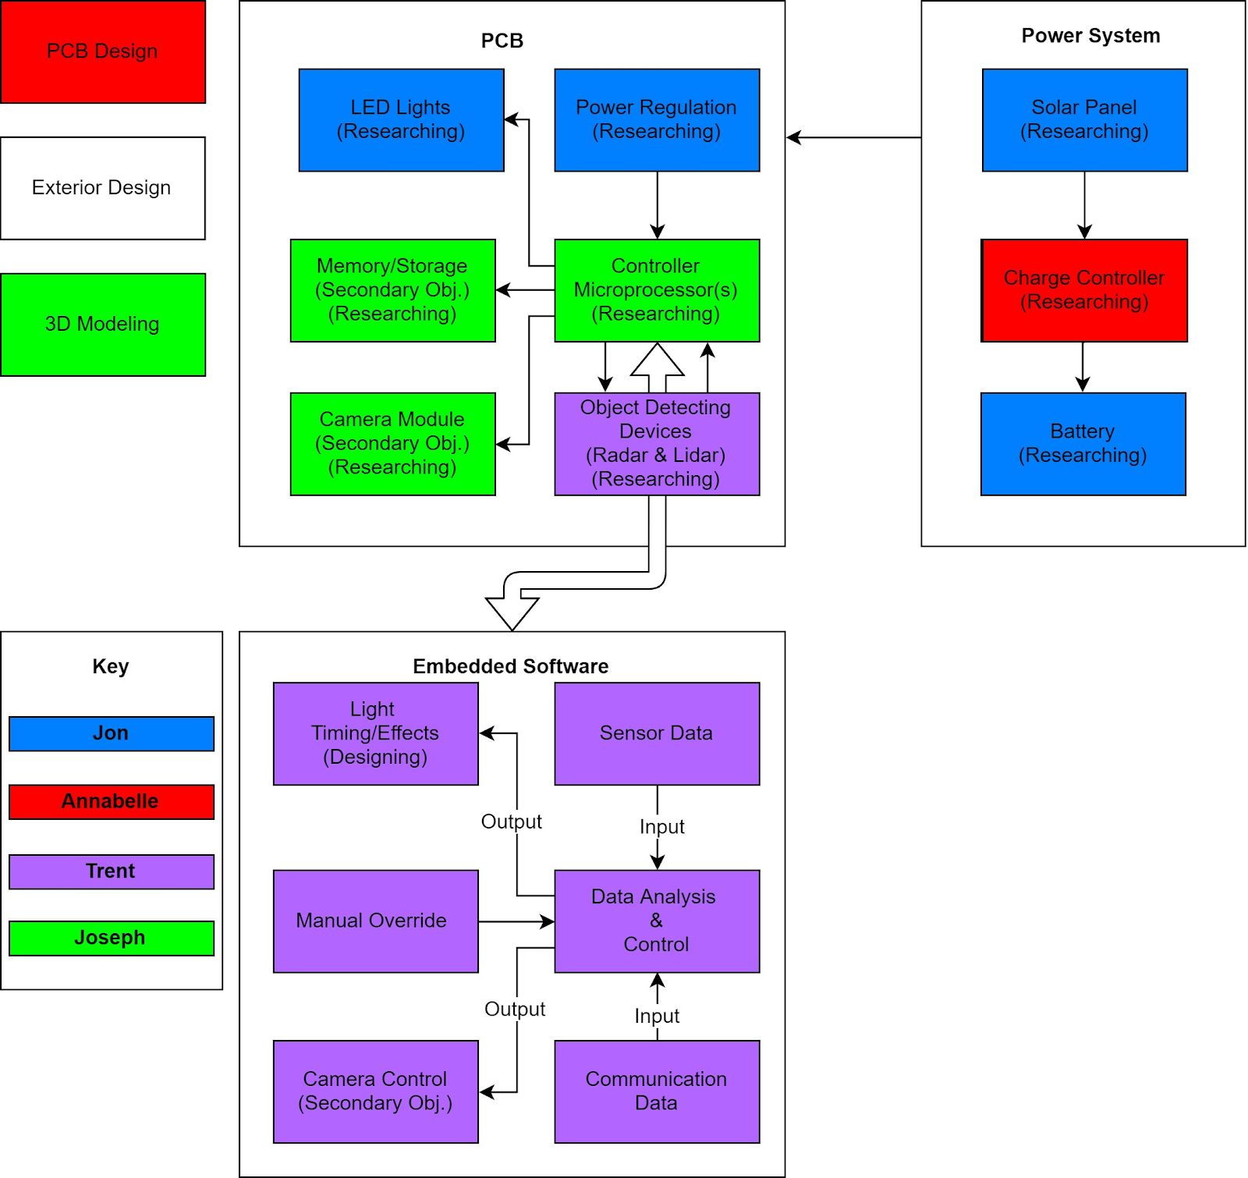
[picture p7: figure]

Figure 2: Full Project Block Diagram

09/27/2018

Estimated Budget & Financing

We are self-funded, and the current budget is around $1000 (estimate). This project is not incredibly expensive but depending on the technology in the sensors and other components it could be more expensive than we currently anticipate. Also, due to the nature of our design, we need to build more than one functional device so that we may test the wireless communication and cross-traffic warning system.

Estimated Costs

Part | Quantity | Unit Price | Total Cost
Solar Panel | 2 | $50 | $100
Battery | 1 | $40 | $40
LEDs | 1 | $40 | $40
Microcontroller | 1 | $10 | $10
PCB | 1 | $20 | $20
Radar | 2 | $33 | $66
Lidar | 2 | $100 | $200
Miscellaneous | 1 | $200 | $200
Cost per unit | 1 | | $676
Table 3: Estimated Budget/Cost for Project

09/27/2018

Senior Design 1 Milestones

Objective | Duration | Start Date | End Date
Senior Design Project Idea | 1 Week | August 20, 2018 | August 24, 2018
Brainstorm Ideas | 2 Weeks | August 25, 2018 | September 7, 2018
Divide and Conquer | 1 Week | September 8, 2018 | September 14, 2018
60 Page Draft | 7 Weeks | September 15, 2018 | November 2, 2018
100 Page Draft | 2 Weeks | November 3, 2018 | November 16, 2018
Rough Draft | 1 Week | November 17,2018 | November 25, 2018
Final Draft | 1 Week | November 26, 2018 | December 3, 2018
Order components | 4 Weeks | December 4, 2018 | January 6, 2019
Table 4: Senior Design 1 Milestones

Senior Design 2 Milestones

Objective | Duration | Start Date | End Date
Build Prototype | 3 Weeks | January 7, 2019 | January 25, 2019
Test Prototype & Redesign | 3 Weeks | January 26, 2019 | February 15, 2019
Finalize Prototype | 2 Weeks | February 16, 2019 | March 1, 2019
Peer Presentation | TBD | TBD | TBD
Final Report | TBD | TBD | TBD
Final Presentation | TBD | TBD | TBD
Table 5: Senior Design 2 Milestones

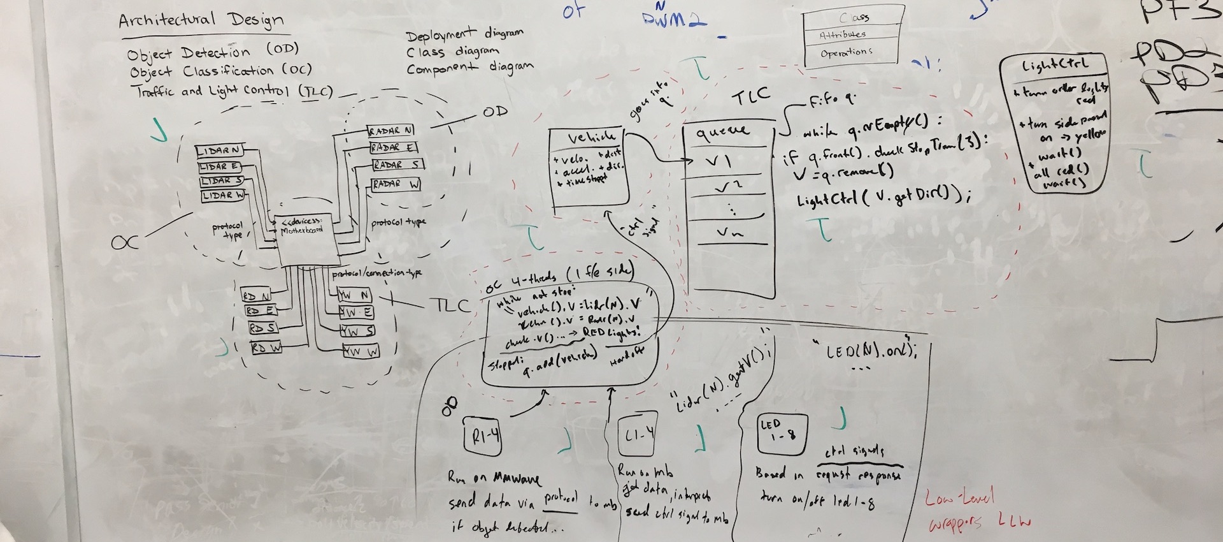
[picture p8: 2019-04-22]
docs/img/Design1.JPG

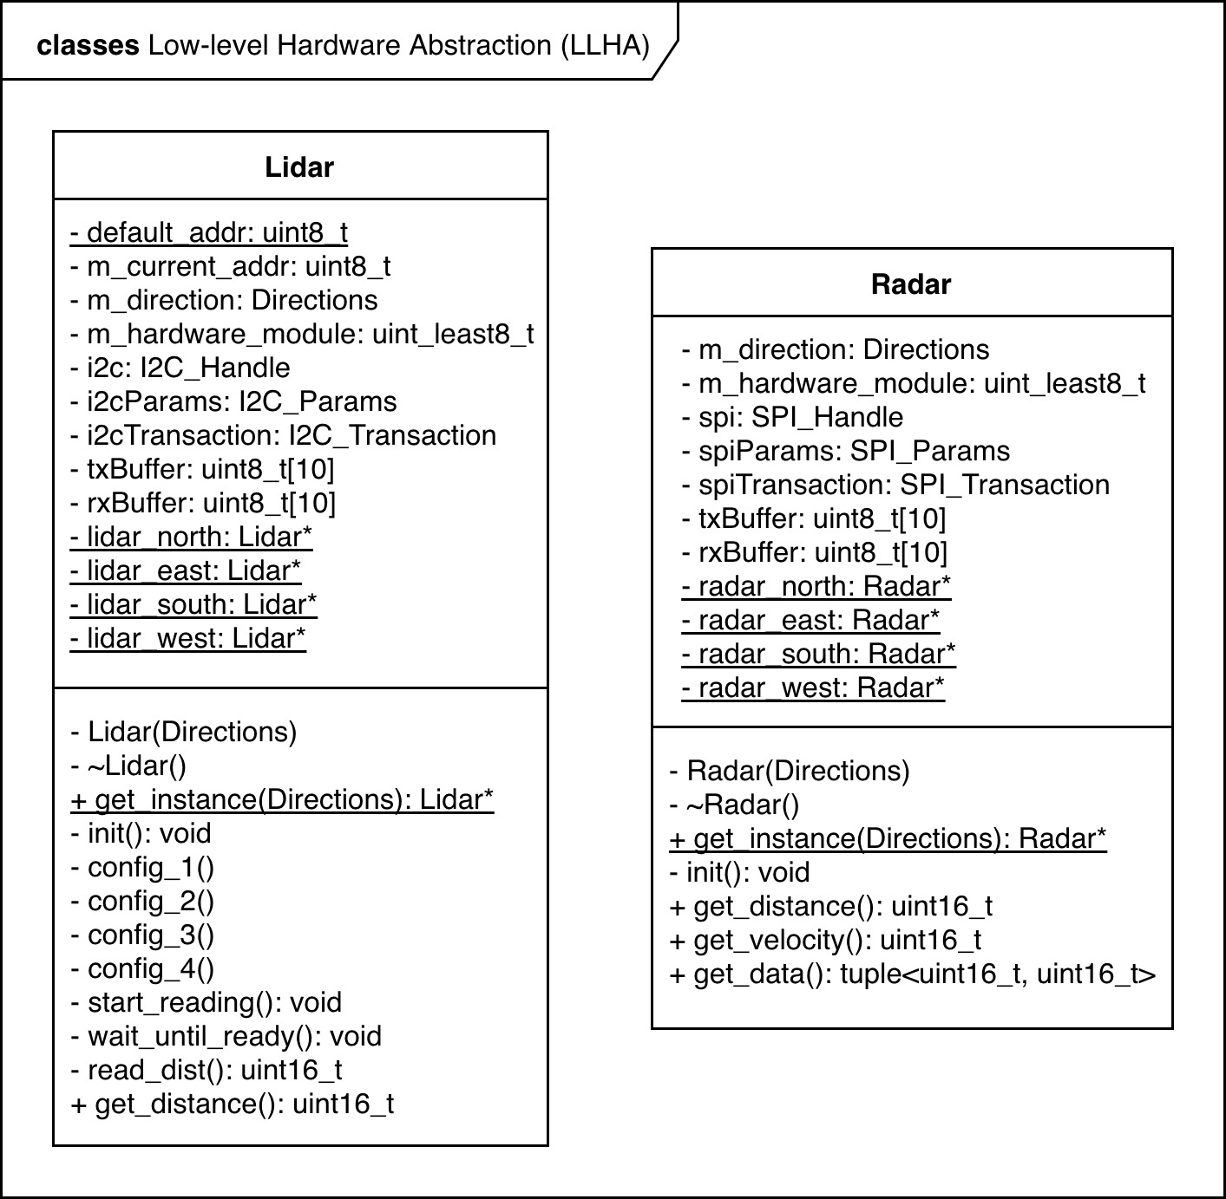
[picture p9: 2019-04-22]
design_artifacts/revised/llha_class_diagram.jpg

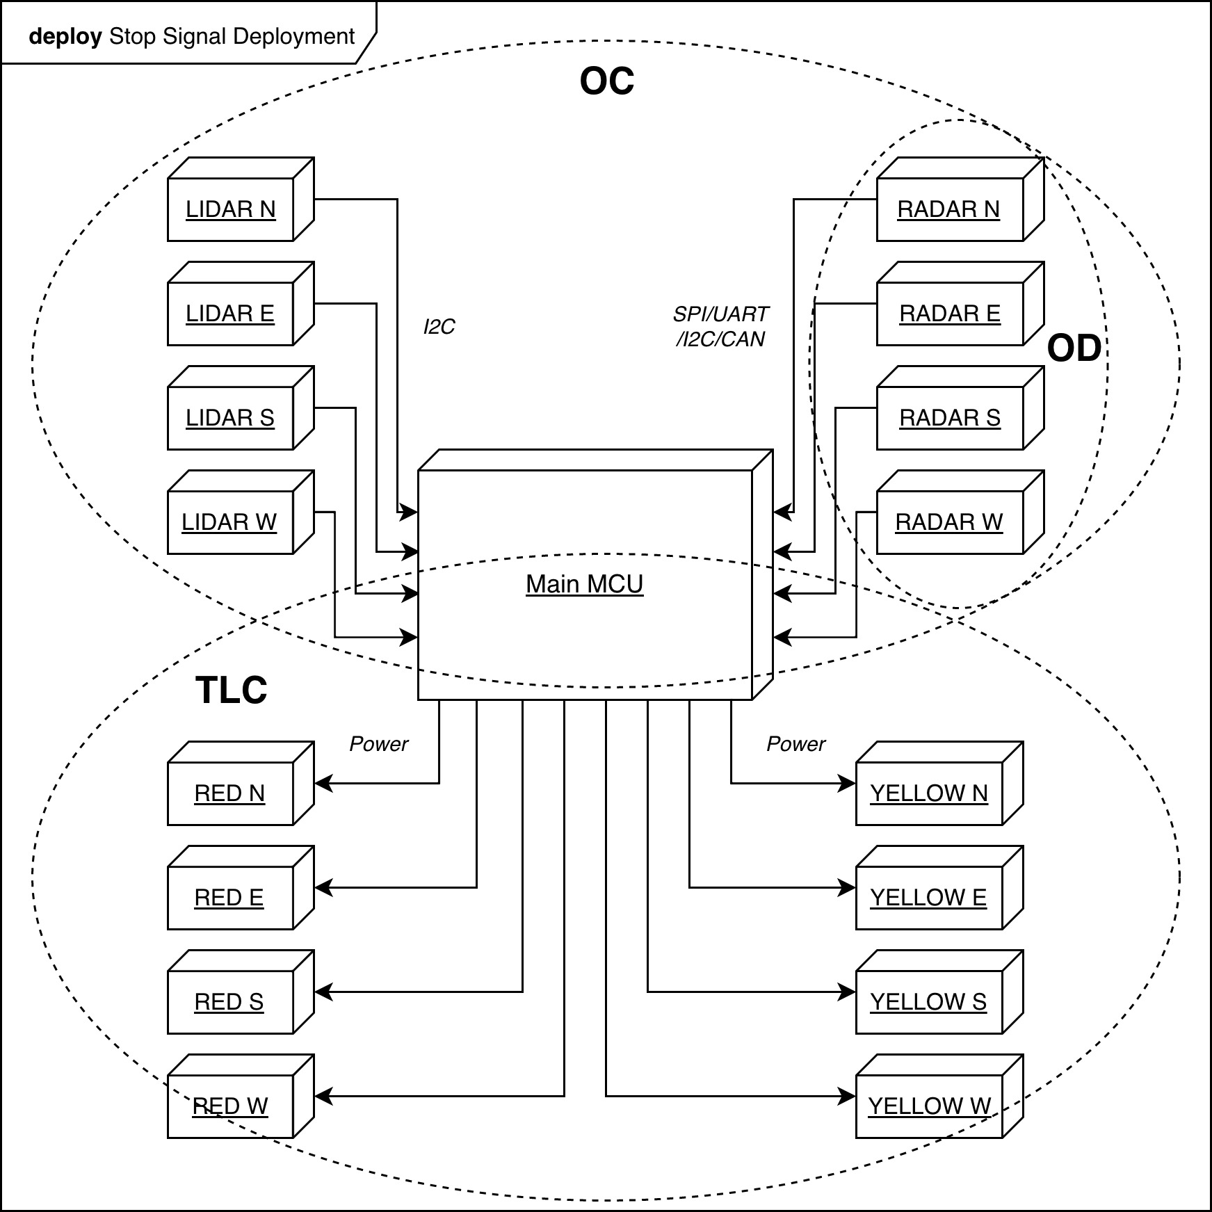
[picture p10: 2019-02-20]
design_artifacts/original/sass_deployment_diagram.jpg

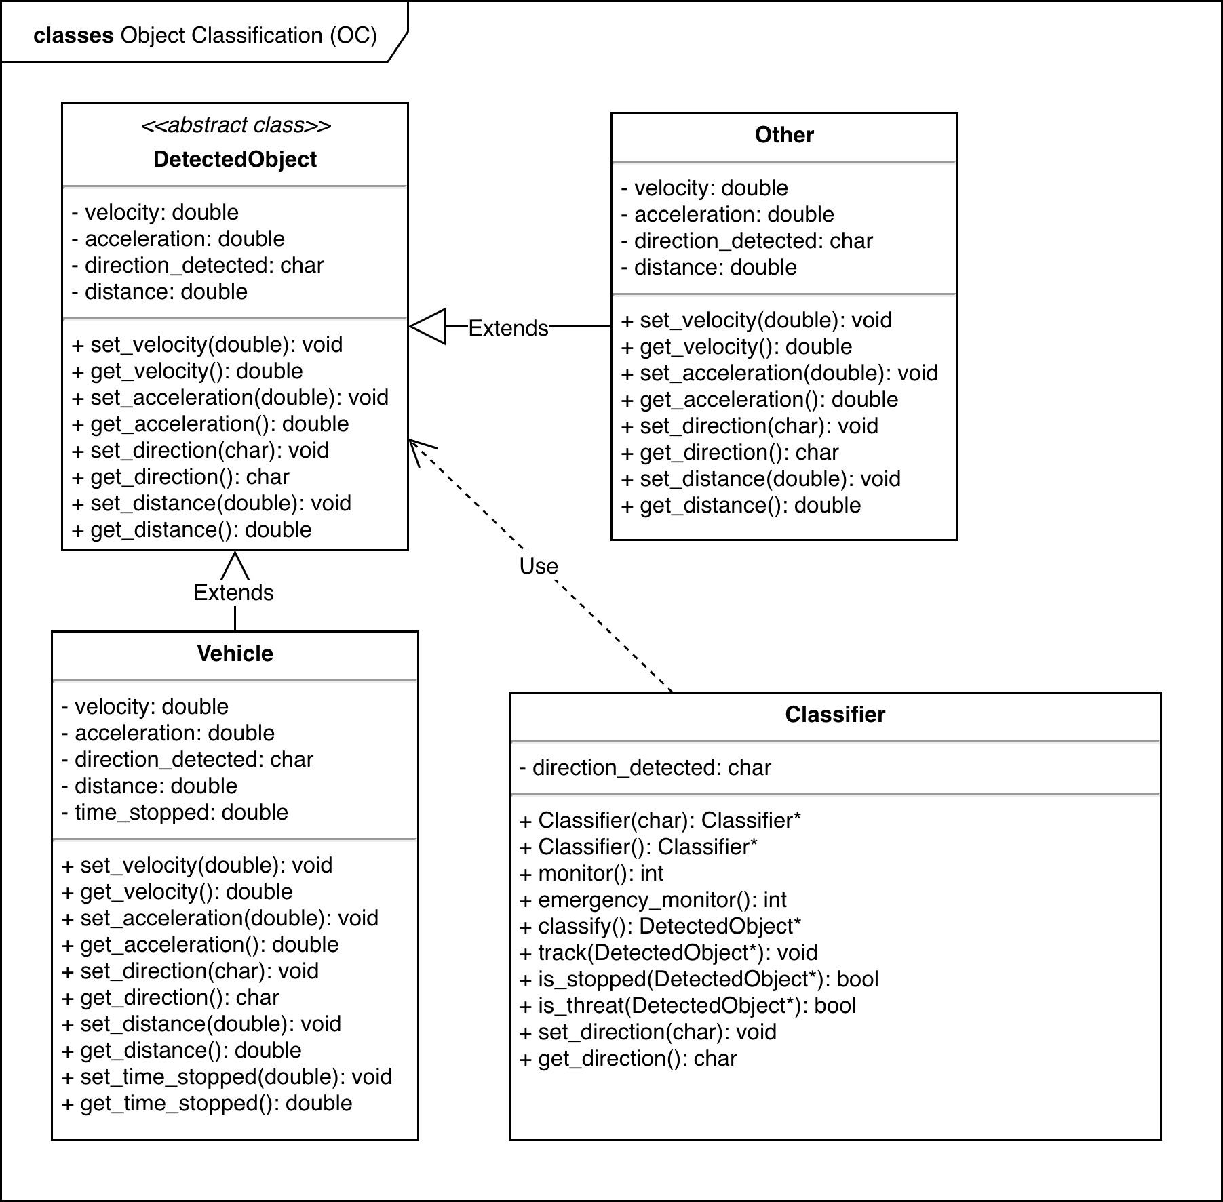
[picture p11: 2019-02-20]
design_artifacts/original/oc_class_diagram.jpg

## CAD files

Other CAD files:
MMWAVE/mmw_dss_16xx/src/sysbios/c64p_Hwi_asm_switch.obj
MMWAVE/mmw_mss_16xx/src/sysbios/arm_IntrinsicsSupport_asm.obj
MMWAVE/mmw_dss_16xx/src/sysbios/c64p_Exception_asm.obj
MMWAVE/mmw_mss_16xx/src/sysbios/tms570_Core_asm.obj
MMWAVE/mmw_mss_16xx/src/sysbios/arm_TaskSupport_asm.obj
MMWAVE/mmw_dss_16xx/src/sysbios/c64p_Hwi_asm.obj
MMWAVE/mmw_mss_16xx/src/sysbios/vim_Hwi_asm_switch.obj
MMWAVE/mmw_dss_16xx/src/sysbios/c62_TaskSupport_asm.obj
MMWAVE/mmw_mss_16xx/src/sysbios/exc_Exception_asm.obj
MMWAVE/mmw_mss_16xx/src/sysbios/vim_Hwi_asm.obj
MMWAVE/mmw_mss_16xx/src/sysbios/BIOS.obj
MMWAVE/mmw_dss_16xx/src/sysbios/c64p_Hwi_disp_always.obj
MMWAVE/mmw_dss_16xx/src/sysbios/BIOS.obj
MMWAVE/mmw_dss_16xx/src/sysbios/ti_tls_get_tp.obj

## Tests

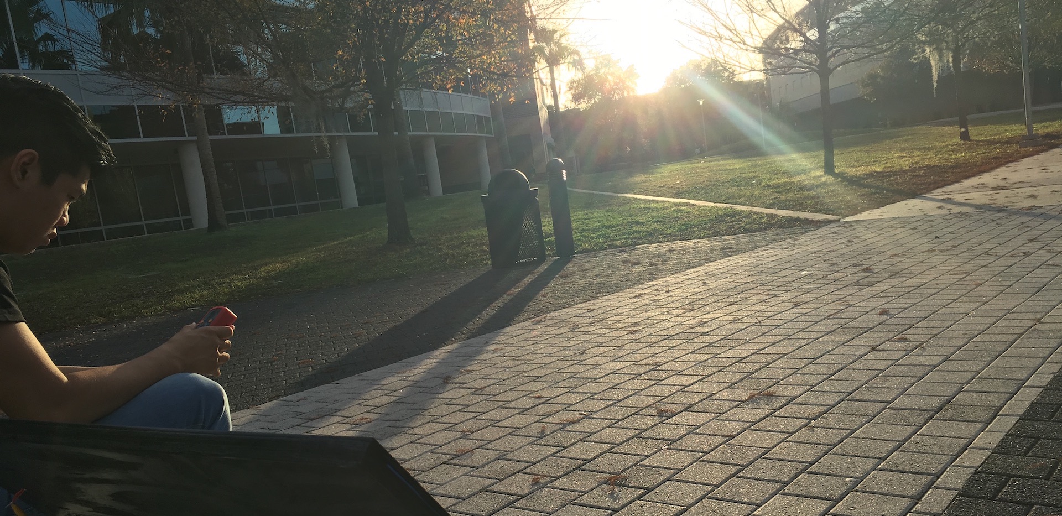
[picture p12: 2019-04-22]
docs/img/shared/SolarPanelTesting3.JPG

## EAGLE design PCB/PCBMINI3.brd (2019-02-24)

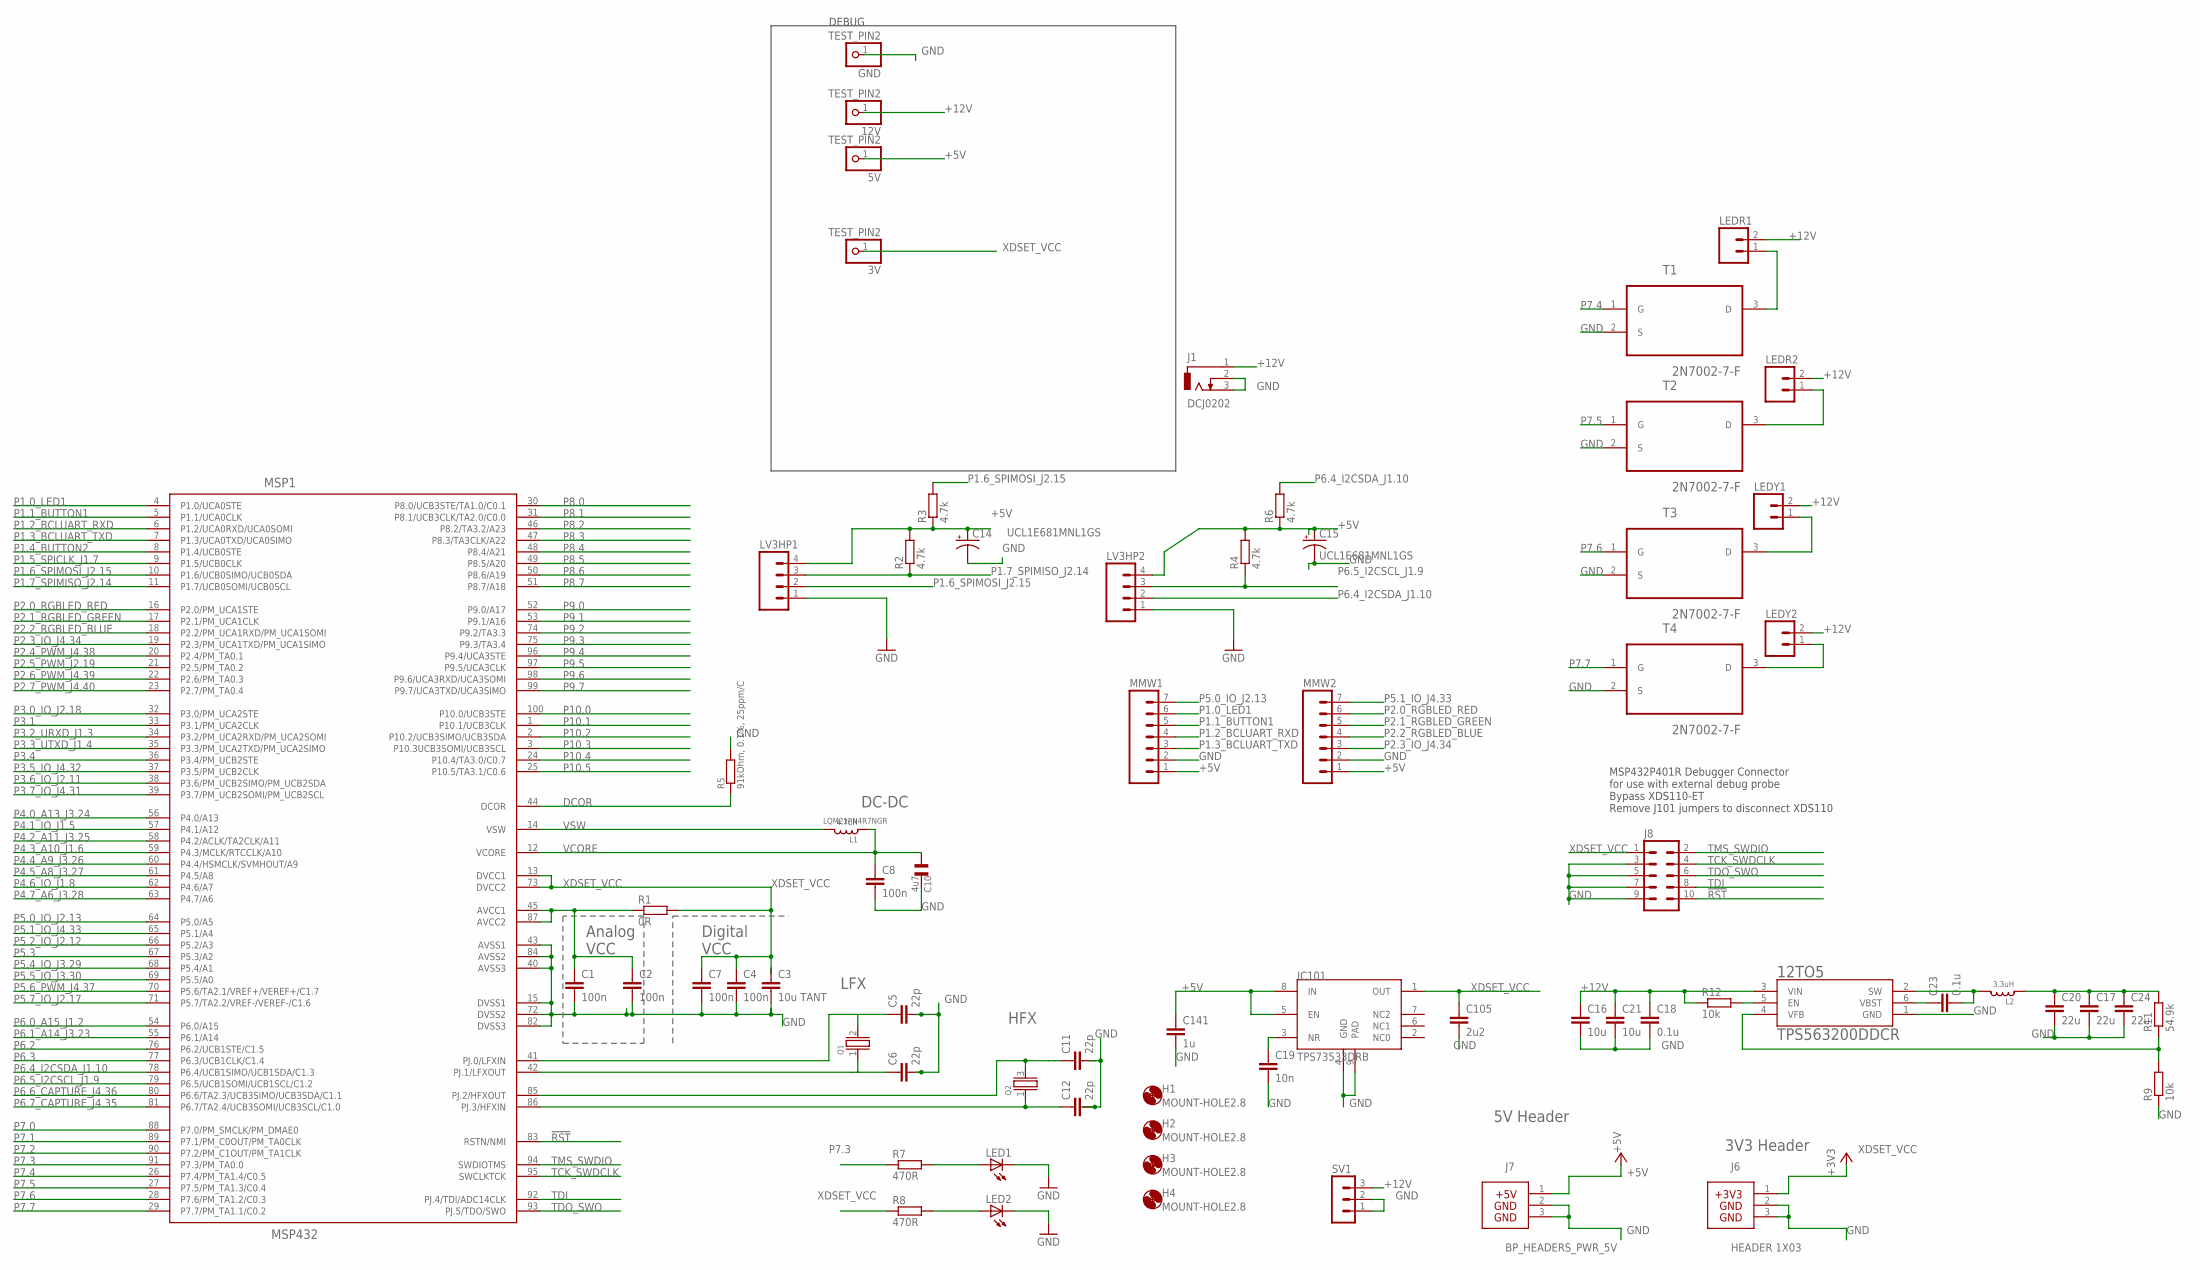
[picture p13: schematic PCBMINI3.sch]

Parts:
3V, 5V, 12V: TEST_PIN2; 1X01
12TO5: TPS563200DDCR; SOT95P280X110-6N
C1, C2, C4, C7, C8: 100n; C0805
C3: 10u TANT; C0805
C5, C6, C11, C12: 22p; C0805
C10: 4u7; CSMD0805
C14, C15: UCL1E681MNL1GS; CAPAE1030X1350N
C16, C21: 10u; C0805
C17, C20, C24: 22u; C0805
C18, C23: 0.1u; C0805
C19: 10n; C0603
C105: 2u2; C0603
C141: 1u; C0603
GND: TEST_PIN2; 1X01
H1, H2, H3, H4: MOUNT-HOLE2.8; 2,8
IC101: TPS73533DRB; SON8
J1: DCJ0202
J6: HEADER 1X03; 3PIN_PWR_3V3
J7: BP_HEADERS_PWR_5V; 3PIN_PWR_5V
J8: DEBUG_ARM-10; ARM-10
L1: 4.7uH; 0806
L2: 3.3uH; 0806
LED1, LED2: LED_E; LED_1206
LEDR1, LEDR2: MA02; 02PA
LEDY1, LEDY2: MA02; 02PA
LV3HP1, LV3HP2: MA04; 04PA
MMW1, MMW2: MA07; 07PA
MSP1: MSP432; PZ100
Q1: CRYSTALLF_GENERAL; LF_XTAL
Q2: CRYSTALEPSON_FA-238; FA-238
R1: 0R; R0805
R2, R3, R4, R6: 4.7k; R0805
R5: 91kOhm, 0.1%, 25ppm/C; 0805
R7, R8: 470R; R0805
R9, R12: 10k; R0805
R11: 54.9k; R0805
SV1: MA03-1
T1, T2, T3, T4: 2N7002-7-F; SOT103P240X110-3N

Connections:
!RST: J8.10, MSP1.83 (RSTN/NMI)
+5V: 5V.1, C14.A (+), C15.A (+), C141.1, IC101.5 (EN), IC101.8 (IN), J7.1, LV3HP1.4, LV3HP2.4, MMW1.1, MMW2.1, R2.2, R3.1, R4.2, R6.1
+12V: 12TO5.3 (VIN), 12V.1, C16.1, C18.1, C21.1, J1.1, LEDR1.2, LEDR2.2, LEDY1.2, LEDY2.2, R12.1, SV1.3
DCOR: MSP1.44 (DCOR), R5.1
GND: 12TO5.1 (GND), C1.2, C2.2, C3.2, C4.2, C5.2, C6.2, C7.2, C8.2, C10.2, C11.2, C12.2, C14.C (-), C15.C (-), C16.2, C17.2, C18.2, C19.2, C20.2, C21.2, C24.2, C105.2, C141.2, GND.1, IC101.4 (GND), IC101.9 (PAD), J1.2, J1.3, J6.2, J6.3, J7.2, J7.3, J8.3, J8.5, J8.7, J8.9, LED1.C, LED2.C, LV3HP1.1, LV3HP2.1, MMW1.2, MMW2.2, MSP1.15 (DVSS1), MSP1.40 (AVSS3), MSP1.43 (AVSS1), MSP1.72 (DVSS2), MSP1.82 (DVSS3), MSP1.84 (AVSS2), R5.2, R9.1, SV1.1, SV1.2, T1.2 (S), T2.2 (S), T3.2 (S), T4.2 (S)
unnamed: LEDY2.1, T4.3 (D)
unnamed: LED1.A, R7.2
unnamed: LED2.A, R8.2
unnamed: 12TO5.5 (EN), R12.2
unnamed: LEDR1.1, T1.3 (D)
unnamed: C1.1, C2.1, MSP1.45 (AVCC1), MSP1.87 (AVCC2), R1.1
unnamed: 12TO5.2 (SW), C23.2, L2.2
unnamed: C17.1, C20.1, C24.1, L2.1, R11.2
unnamed: LEDR2.1, T2.3 (D)
unnamed: C19.1, IC101.3 (NR)
unnamed: 12TO5.6 (VBST), C23.1
unnamed: 12TO5.4 (VFB), R9.2, R11.1
unnamed: C6.1, MSP1.42 (PJ.1/LFXOUT), Q1.1
unnamed: C5.1, MSP1.41 (PJ.0/LFXIN), Q1.2
P1.0_LED1: MMW1.6, MSP1.4 (P1.0/UCA0STE)
P1.1_BUTTON1: MMW1.5, MSP1.5 (P1.1/UCA0CLK)
P1.2_BCLUART_RXD: MMW1.4, MSP1.6 (P1.2/UCA0RXD/UCA0SOMI)
P1.3_BCLUART_TXD: MMW1.3, MSP1.7 (P1.3/UCA0TXD/UCA0SIMO)
P1.4_BUTTON2: MSP1.8 (P1.4/UCB0STE)
P1.5_SPICLK_J1.7: MSP1.9 (P1.5/UCB0CLK)
P1.6_SPIMOSI_J2.15: LV3HP1.2, MSP1.10 (P1.6/UCB0SIMO/UCB0SDA), R3.2
P1.7_SPIMISO_J2.14: LV3HP1.3, MSP1.11 (P1.7/UCB0SOMI/UCB0SCL), R2.1
P2.0_RGBLED_RED: MMW2.6, MSP1.16 (P2.0/PM_UCA1STE)
P2.1_RGBLED_GREEN: MMW2.5, MSP1.17 (P2.1/PM_UCA1CLK)
P2.2_RGBLED_BLUE: MMW2.4, MSP1.18 (P2.2/PM_UCA1RXD/PM_UCA1SOMI)
P2.3_IO_J4.34: MMW2.3, MSP1.19 (P2.3/PM_UCA1TXD/PM_UCA1SIMO)
P2.4_PWM_J4.38: MSP1.20 (P2.4/PM_TA0.1)
P2.5_PWM_J2.19: MSP1.21 (P2.5/PM_TA0.2)
P2.6_PWM_J4.39: MSP1.22 (P2.6/PM_TA0.3)
P2.7_PWM_J4.40: MSP1.23 (P2.7/PM_TA0.4)
P3.0_IO_J2.18: MSP1.32 (P3.0/PM_UCA2STE)
P3.1: MSP1.33 (P3.1/PM_UCA2CLK)
P3.2_URXD_J1.3: MSP1.34 (P3.2/PM_UCA2RXD/PM_UCA2SOMI)
P3.3_UTXD_J1.4: MSP1.35 (P3.3/PM_UCA2TXD/PM_UCA2SIMO)
P3.4: MSP1.36 (P3.4/PM_UCB2STE)
P3.5_IO_J4.32: MSP1.37 (P3.5/PM_UCB2CLK)
P3.6_IO_J2.11: MSP1.38 (P3.6/PM_UCB2SIMO/PM_UCB2SDA)
P3.7_IO_J4.31: MSP1.39 (P3.7/PM_UCB2SOMI/PM_UCB2SCL)
P4.0_A13_J3.24: MSP1.56 (P4.0/A13)
P4.1_IO_J1.5: MSP1.57 (P4.1/A12)
P4.2_A11_J3.25: MSP1.58 (P4.2/ACLK/TA2CLK/A11)
P4.3_A10_J1.6: MSP1.59 (P4.3/MCLK/RTCCLK/A10)
P4.4_A9_J3.26: MSP1.60 (P4.4/HSMCLK/SVMHOUT/A9)
P4.5_A8_J3.27: MSP1.61 (P4.5/A8)
P4.6_IO_J1.8: MSP1.62 (P4.6/A7)
P4.7_A6_J3.28: MSP1.63 (P4.7/A6)
P5.0_IO_J2.13: MMW1.7, MSP1.64 (P5.0/A5)
P5.1_IO_J4.33: MMW2.7, MSP1.65 (P5.1/A4)
P5.2/XT2IN: C12.1, MSP1.86 (PJ.3/HFXIN), Q2.1
P5.2_IO_J2.12: MSP1.66 (P5.2/A3)
P5.3: MSP1.67 (P5.3/A2)
P5.3/XT2OUT: C11.1, MSP1.85 (PJ.2/HFXOUT), Q2.3 (2)
P5.4_IO_J3.29: MSP1.68 (P5.4/A1)
P5.5_IO_J3.30: MSP1.69 (P5.5/A0)
P5.6_PWM_J4.37: MSP1.70 (P5.6/TA2.1/VREF+/VEREF+/C1.7)
P5.7_IO_J2.17: MSP1.71 (P5.7/TA2.2/VREF-/VEREF-/C1.6)
P6.0_A15_J1.2: MSP1.54 (P6.0/A15)
P6.1_A14_J3.23: MSP1.55 (P6.1/A14)
P6.2: MSP1.76 (P6.2/UCB1STE/C1.5)
P6.3: MSP1.77 (P6.3/UCB1CLK/C1.4)
P6.4_I2CSDA_J1.10: LV3HP2.2, MSP1.78 (P6.4/UCB1SIMO/UCB1SDA/C1.3), R6.2
P6.5_I2CSCL_J1.9: LV3HP2.3, MSP1.79 (P6.5/UCB1SOMI/UCB1SCL/C1.2), R4.1
P6.6_CAPTURE_J4.36: MSP1.80 (P6.6/TA2.3/UCB3SIMO/UCB3SDA/C1.1)
P6.7_CAPTURE_J4.35: MSP1.81 (P6.7/TA2.4/UCB3SOMI/UCB3SCL/C1.0)
P7.0: MSP1.88 (P7.0/PM_SMCLK/PM_DMAE0)
P7.1: MSP1.89 (P7.1/PM_C0OUT/PM_TA0CLK)
P7.2: MSP1.90 (P7.2/PM_C1OUT/PM_TA1CLK)
P7.3: MSP1.91 (P7.3/PM_TA0.0), R7.1
P7.4: MSP1.26 (P7.4/PM_TA1.4/C0.5), T1.1 (G)
P7.5: MSP1.27 (P7.5/PM_TA1.3/C0.4), T2.1 (G)
P7.6: MSP1.28 (P7.6/PM_TA1.2/C0.3), T3.1 (G)
P7.7: MSP1.29 (P7.7/PM_TA1.1/C0.2), T4.1 (G)
P8.0: MSP1.30 (P8.0/UCB3STE/TA1.0/C0.1)
P8.1: MSP1.31 (P8.1/UCB3CLK/TA2.0/C0.0)
P8.2: MSP1.46 (P8.2/TA3.2/A23)
P8.3: MSP1.47 (P8.3/TA3CLK/A22)
P8.4: MSP1.48 (P8.4/A21)
P8.5: MSP1.49 (P8.5/A20)
P8.6: MSP1.50 (P8.6/A19)
P8.7: MSP1.51 (P8.7/A18)
P9.0: MSP1.52 (P9.0/A17)
P9.1: MSP1.53 (P9.1/A16)
P9.2: MSP1.74 (P9.2/TA3.3)
P9.3: MSP1.75 (P9.3/TA3.4)
P9.4: MSP1.96 (P9.4/UCA3STE)
P9.5: MSP1.97 (P9.5/UCA3CLK)
P9.6: MSP1.98 (P9.6/UCA3RXD/UCA3SOMI)
P9.7: MSP1.99 (P9.7/UCA3TXD/UCA3SIMO)
P10.0: MSP1.100 (P10.0/UCB3STE)
P10.1: MSP1.1 (P10.1/UCB3CLK)
P10.2: MSP1.2 (P10.2/UCB3SIMO/UCB3SDA)
P10.3: MSP1.3 (P10.3UCB3SOMI/UCB3SCL)
P10.4: MSP1.24 (P10.4/TA3.0/C0.7)
P10.5: MSP1.25 (P10.5/TA3.1/C0.6)
TCK_SWDCLK: J8.4, MSP1.95 (SWCLKTCK)
TDI: J8.8, MSP1.92 (PJ.4/TDI/ADC14CLK)
TDO_SWO: J8.6, MSP1.93 (PJ.5/TDO/SWO)
TMS_SWDIO: J8.2, MSP1.94 (SWDIOTMS)
VCORE: C8.1, C10.1, L1.1, MSP1.12 (VCORE)
VSW: L1.2, MSP1.14 (VSW)
XDSET_VCC: 3V.1, C3.1, C4.1, C7.1, C105.1, IC101.1 (OUT), J6.1, J8.1, MSP1.13 (DVCC1), MSP1.73 (DVCC2), R1.2, R8.1
Y1: LEDY1.1, T3.3 (D)

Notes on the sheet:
LQM21PN4R7NGR
HFX
LFX
Analog
VCC
Digital
DC-DC
5V Header
MSP432P401R Debugger Connector for use with external debug probe Bypass XDS110-ET Remove J101 jumpers to disconnect XDS110
3V3 Header
DEBUG

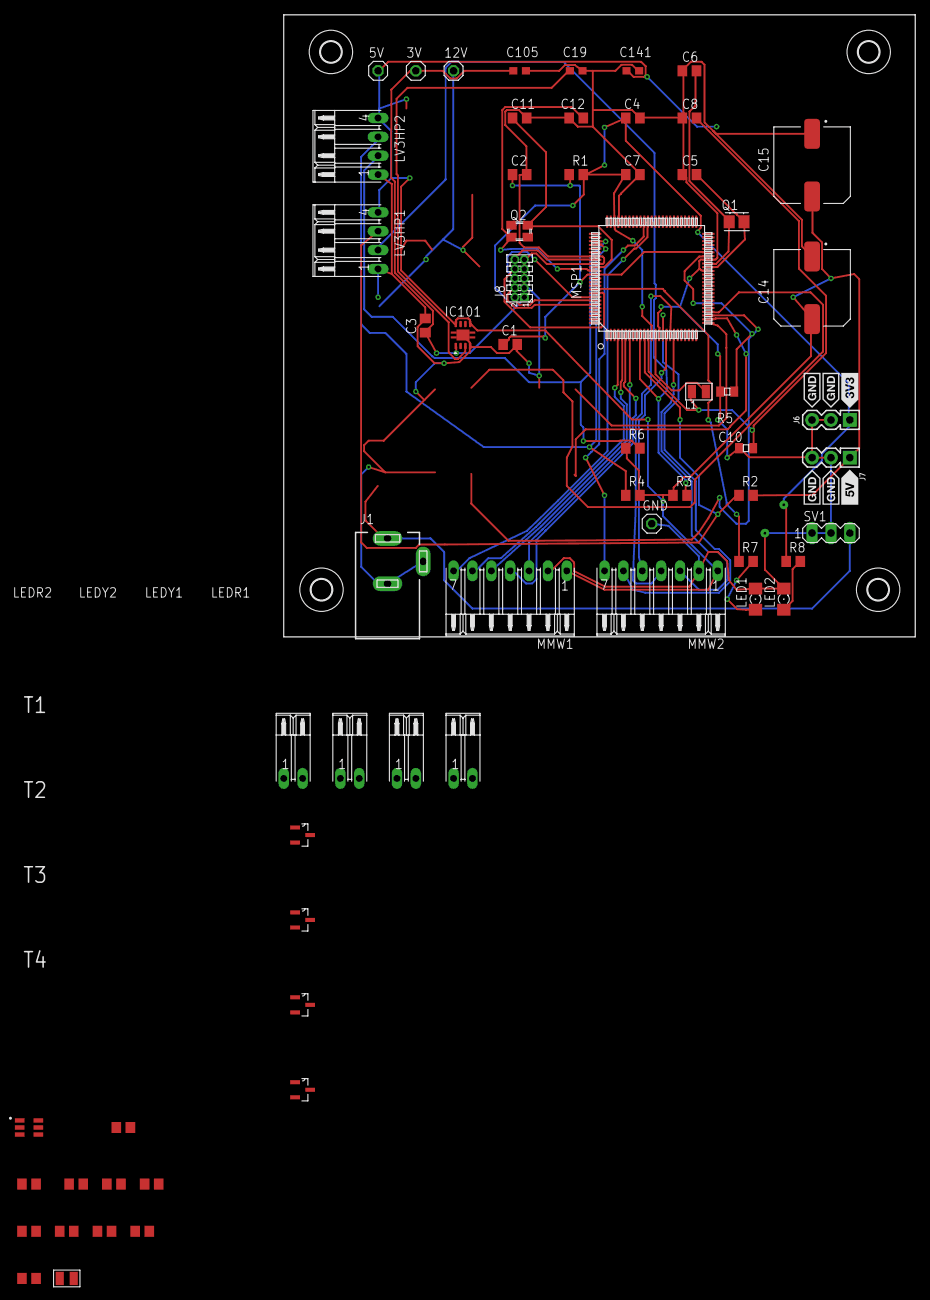
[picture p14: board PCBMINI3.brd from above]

Board: 2 copper layers, 85.0 x 83.7 mm, 68 parts (0 on the bottom side), 48 nets.

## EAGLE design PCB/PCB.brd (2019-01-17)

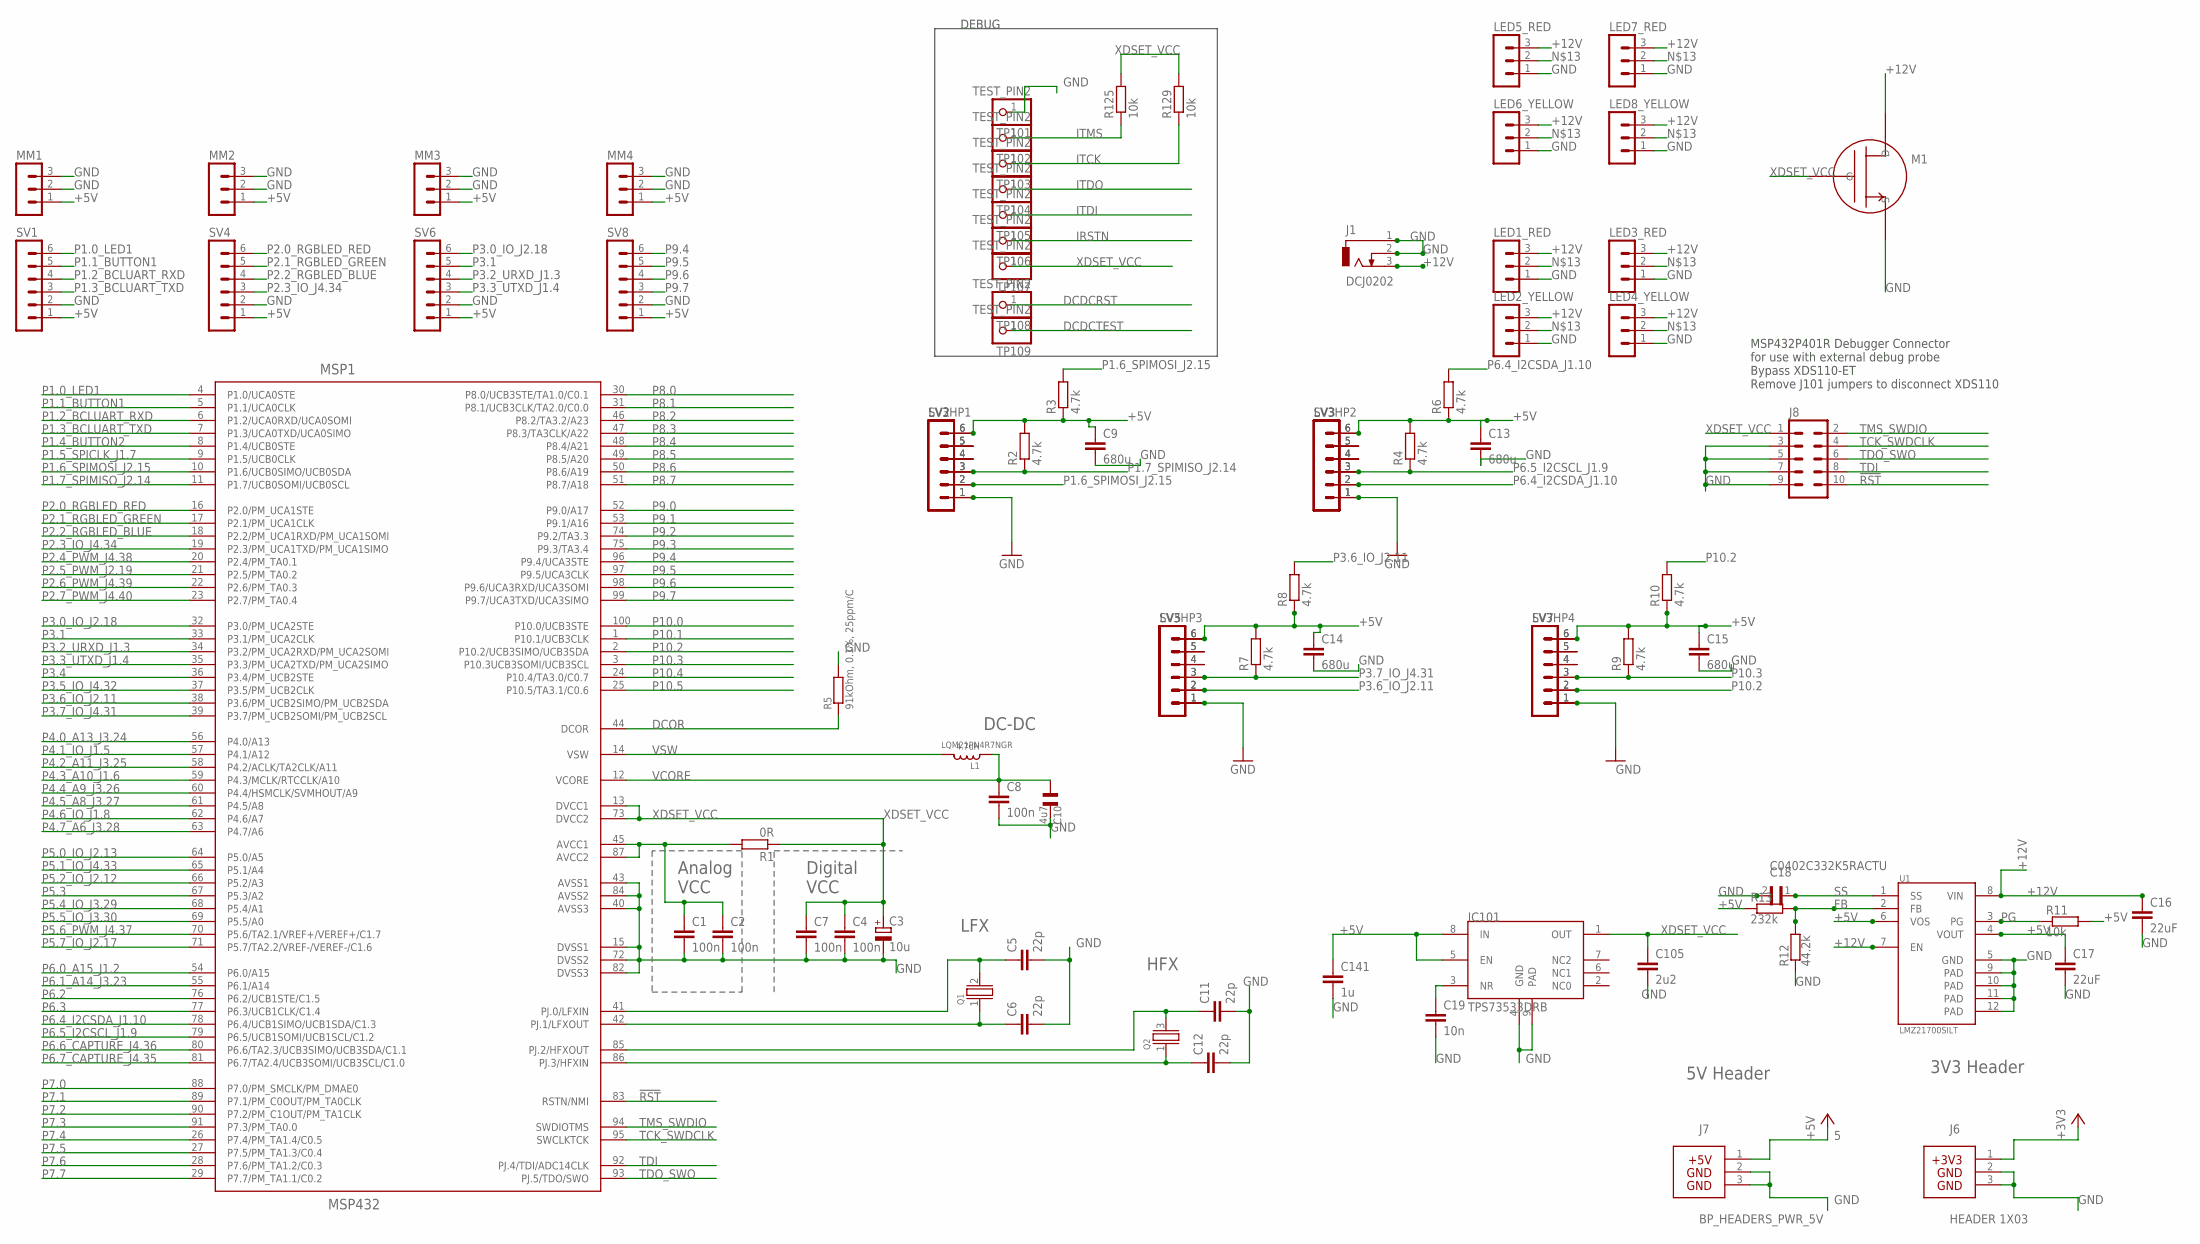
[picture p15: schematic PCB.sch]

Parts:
C1, C2, C4, C7, C8: 100n; 0402
C3: 10u; A/3216-18R
C5, C6, C11, C12: 22p; 0402
C9, C13, C14, C15: 680u; 0402
C10: 4u7; CSMD0805
C16, C17: 22uF; 0805
C18: C0402C332K5RACTU; CAPC1005X55N
C19: 10n; C0603
C105: 2u2; C0603
C141: 1u; C0603
IC101: TPS73533DRB; SON8
J1: DCJ0202
J6: HEADER 1X03; 3PIN_PWR_3V3
J7: BP_HEADERS_PWR_5V; 3PIN_PWR_5V
J8: DEBUG_ARM-10; ARM-10
L1: 4.7uH; 0806
LED1_RED, LED2_YELLOW, LED3_RED, LED4_YELLOW, LED5_RED, LED6_YELLOW, LED7_RED, LED8_YELLOW: MA03-1
LV3HP1, LV3HP2, LV3HP3, LV3HP4: MA06-1
MM1, MM2, MM3, MM4: MA03-1
MSP1: MSP432; PZ100
Q1: CRYSTALLF_GENERAL; LF_XTAL
Q2: CRYSTALEPSON_FA-238; FA-238
R1: 0R; 0402
R2, R3, R4, R6, R7, R8, R9, R10: 4.7k; 0402
R5: 91kOhm, 0.1%, 25ppm/C; 0805
R11: 10k; SMK
R12: 44.2k; SMK
R13: 232k; SMK
R125, R129: 10k; 0402
SV1, SV2, SV3, SV4, SV5, SV6, SV7, SV8: MA06-1
TP101, TP102, TP103, TP104, TP105, TP106, TP107, TP108, TP109: TEST_PIN2; 1X01
U1: LMZ21700SILT; DFN350X350X175-10RN

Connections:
5: J7.1
!RST: J8.10, MSP1.83 (RSTN/NMI)
+3V3: J6.1
+5V: C9.1, C13.1, C14.1, C15.1, C17.1, C141.1, IC101.5 (EN), IC101.8 (IN), LV3HP1.6, LV3HP2.6, LV3HP3.6, LV3HP4.6, MM1.1, MM2.1, MM3.1, MM4.1, R2.2, R3.1, R4.2, R6.1, R7.2, R8.1, R9.2, R10.1, R11.1, R13.2, SV1.1, SV2.6, SV3.6, SV4.1, SV5.6, SV6.1, SV7.6, SV8.1, U1.4 (VOUT), U1.6 (VOS)
+12V: C16.1, J1.3, LED1_RED.3, LED2_YELLOW.3, LED3_RED.3, LED4_YELLOW.3, LED5_RED.3, LED6_YELLOW.3, LED7_RED.3, LED8_YELLOW.3, U1.7 (EN), U1.8 (VIN)
DCDCRST: TP108.1
DCDCTEST: TP109.1
DCOR: MSP1.44 (DCOR), R5.1
FB: R12.1, R13.1, U1.2 (FB)
GND: C1.2, C2.2, C3.-, C4.2, C5.2, C6.2, C7.2, C8.2, C9.2, C10.2, C11.2, C12.2, C13.2, C14.2, C15.2, C16.2, C17.2, C18.2, C19.2, C105.2, C141.2, IC101.4 (GND), IC101.9 (PAD), J1.1, J1.2, J6.2, J6.3, J7.2, J7.3, J8.3, J8.5, J8.7, J8.9, LED1_RED.1, LED2_YELLOW.1, LED3_RED.1, LED4_YELLOW.1, LED5_RED.1, LED6_YELLOW.1, LED7_RED.1, LED8_YELLOW.1, LV3HP1.1, LV3HP2.1, LV3HP3.1, LV3HP4.1, MM1.2, MM1.3, MM2.2, MM2.3, MM3.2, MM3.3, MM4.2, MM4.3, MSP1.15 (DVSS1), MSP1.40 (AVSS3), MSP1.43 (AVSS1), MSP1.72 (DVSS2), MSP1.82 (DVSS3), MSP1.84 (AVSS2), R5.2, R12.2, SV1.2, SV2.1, SV3.1, SV4.2, SV5.1, SV6.2, SV7.1, SV8.2, TP101.1
IRSTN: TP106.1
ITCK: R129.1, TP103.1
ITDI: TP105.1
ITDO: TP104.1
ITMS: R125.1, TP102.1
unnamed: LV3HP2.4, SV3.4
unnamed: LV3HP2.5, SV3.5
unnamed: LV3HP3.4, SV5.4
unnamed: LV3HP1.4, SV2.4
unnamed: LV3HP1.5, SV2.5
unnamed: C1.1, C2.1, MSP1.45 (AVCC1), MSP1.87 (AVCC2), R1.2
unnamed: LV3HP3.5, SV5.5
unnamed: LV3HP4.4, SV7.4
unnamed: LV3HP4.5, SV7.5
unnamed: U1.5 (GND), U1.9 (PAD), U1.10 (PAD), U1.11 (PAD), U1.12 (PAD)
unnamed: C19.1, IC101.3 (NR)
unnamed: LED1_RED.2, LED2_YELLOW.2, LED3_RED.2, LED4_YELLOW.2, LED5_RED.2, LED6_YELLOW.2, LED7_RED.2, LED8_YELLOW.2
unnamed: C6.1, MSP1.42 (PJ.1/LFXOUT), Q1.1
unnamed: C5.1, MSP1.41 (PJ.0/LFXIN), Q1.2
P1.0_LED1: MSP1.4 (P1.0/UCA0STE), SV1.6
P1.1_BUTTON1: MSP1.5 (P1.1/UCA0CLK), SV1.5
P1.2_BCLUART_RXD: MSP1.6 (P1.2/UCA0RXD/UCA0SOMI), SV1.4
P1.3_BCLUART_TXD: MSP1.7 (P1.3/UCA0TXD/UCA0SIMO), SV1.3
P1.4_BUTTON2: MSP1.8 (P1.4/UCB0STE)
P1.5_SPICLK_J1.7: MSP1.9 (P1.5/UCB0CLK)
P1.6_SPIMOSI_J2.15: LV3HP1.2, MSP1.10 (P1.6/UCB0SIMO/UCB0SDA), R3.2, SV2.2
P1.7_SPIMISO_J2.14: LV3HP1.3, MSP1.11 (P1.7/UCB0SOMI/UCB0SCL), R2.1, SV2.3
P2.0_RGBLED_RED: MSP1.16 (P2.0/PM_UCA1STE), SV4.6
P2.1_RGBLED_GREEN: MSP1.17 (P2.1/PM_UCA1CLK), SV4.5
P2.2_RGBLED_BLUE: MSP1.18 (P2.2/PM_UCA1RXD/PM_UCA1SOMI), SV4.4
P2.3_IO_J4.34: MSP1.19 (P2.3/PM_UCA1TXD/PM_UCA1SIMO), SV4.3
P2.4_PWM_J4.38: MSP1.20 (P2.4/PM_TA0.1)
P2.5_PWM_J2.19: MSP1.21 (P2.5/PM_TA0.2)
P2.6_PWM_J4.39: MSP1.22 (P2.6/PM_TA0.3)
P2.7_PWM_J4.40: MSP1.23 (P2.7/PM_TA0.4)
P3.0_IO_J2.18: MSP1.32 (P3.0/PM_UCA2STE), SV6.6
P3.1: MSP1.33 (P3.1/PM_UCA2CLK), SV6.5
P3.2_URXD_J1.3: MSP1.34 (P3.2/PM_UCA2RXD/PM_UCA2SOMI), SV6.4
P3.3_UTXD_J1.4: MSP1.35 (P3.3/PM_UCA2TXD/PM_UCA2SIMO), SV6.3
P3.4: MSP1.36 (P3.4/PM_UCB2STE)
P3.5_IO_J4.32: MSP1.37 (P3.5/PM_UCB2CLK)
P3.6_IO_J2.11: LV3HP3.2, MSP1.38 (P3.6/PM_UCB2SIMO/PM_UCB2SDA), R8.2, SV5.2
P3.7_IO_J4.31: LV3HP3.3, MSP1.39 (P3.7/PM_UCB2SOMI/PM_UCB2SCL), R7.1, SV5.3
P4.0_A13_J3.24: MSP1.56 (P4.0/A13)
P4.1_IO_J1.5: MSP1.57 (P4.1/A12)
P4.2_A11_J3.25: MSP1.58 (P4.2/ACLK/TA2CLK/A11)
P4.3_A10_J1.6: MSP1.59 (P4.3/MCLK/RTCCLK/A10)
P4.4_A9_J3.26: MSP1.60 (P4.4/HSMCLK/SVMHOUT/A9)
P4.5_A8_J3.27: MSP1.61 (P4.5/A8)
P4.6_IO_J1.8: MSP1.62 (P4.6/A7)
P4.7_A6_J3.28: MSP1.63 (P4.7/A6)
P5.0_IO_J2.13: MSP1.64 (P5.0/A5)
P5.1_IO_J4.33: MSP1.65 (P5.1/A4)
P5.2/XT2IN: C12.1, MSP1.86 (PJ.3/HFXIN), Q2.1
P5.2_IO_J2.12: MSP1.66 (P5.2/A3)
P5.3: MSP1.67 (P5.3/A2)
P5.3/XT2OUT: C11.1, MSP1.85 (PJ.2/HFXOUT), Q2.3 (2)
P5.4_IO_J3.29: MSP1.68 (P5.4/A1)
P5.5_IO_J3.30: MSP1.69 (P5.5/A0)
P5.6_PWM_J4.37: MSP1.70 (P5.6/TA2.1/VREF+/VEREF+/C1.7)
P5.7_IO_J2.17: MSP1.71 (P5.7/TA2.2/VREF-/VEREF-/C1.6)
P6.0_A15_J1.2: MSP1.54 (P6.0/A15)
P6.1_A14_J3.23: MSP1.55 (P6.1/A14)
P6.2: MSP1.76 (P6.2/UCB1STE/C1.5)
P6.3: MSP1.77 (P6.3/UCB1CLK/C1.4)
P6.4_I2CSDA_J1.10: LV3HP2.2, MSP1.78 (P6.4/UCB1SIMO/UCB1SDA/C1.3), R6.2, SV3.2
P6.5_I2CSCL_J1.9: LV3HP2.3, MSP1.79 (P6.5/UCB1SOMI/UCB1SCL/C1.2), R4.1, SV3.3
P6.6_CAPTURE_J4.36: MSP1.80 (P6.6/TA2.3/UCB3SIMO/UCB3SDA/C1.1)
P6.7_CAPTURE_J4.35: MSP1.81 (P6.7/TA2.4/UCB3SOMI/UCB3SCL/C1.0)
P7.0: MSP1.88 (P7.0/PM_SMCLK/PM_DMAE0)
P7.1: MSP1.89 (P7.1/PM_C0OUT/PM_TA0CLK)
P7.2: MSP1.90 (P7.2/PM_C1OUT/PM_TA1CLK)
P7.3: MSP1.91 (P7.3/PM_TA0.0)
P7.4: MSP1.26 (P7.4/PM_TA1.4/C0.5)
P7.5: MSP1.27 (P7.5/PM_TA1.3/C0.4)
P7.6: MSP1.28 (P7.6/PM_TA1.2/C0.3)
P7.7: MSP1.29 (P7.7/PM_TA1.1/C0.2)
P8.0: MSP1.30 (P8.0/UCB3STE/TA1.0/C0.1)
P8.1: MSP1.31 (P8.1/UCB3CLK/TA2.0/C0.0)
P8.2: MSP1.46 (P8.2/TA3.2/A23)
P8.3: MSP1.47 (P8.3/TA3CLK/A22)
P8.4: MSP1.48 (P8.4/A21)
P8.5: MSP1.49 (P8.5/A20)
P8.6: MSP1.50 (P8.6/A19)
P8.7: MSP1.51 (P8.7/A18)
P9.0: MSP1.52 (P9.0/A17)
P9.1: MSP1.53 (P9.1/A16)
P9.2: MSP1.74 (P9.2/TA3.3)
P9.3: MSP1.75 (P9.3/TA3.4)
P9.4: MSP1.96 (P9.4/UCA3STE), SV8.6
P9.5: MSP1.97 (P9.5/UCA3CLK), SV8.5
P9.6: MSP1.98 (P9.6/UCA3RXD/UCA3SOMI), SV8.4
P9.7: MSP1.99 (P9.7/UCA3TXD/UCA3SIMO), SV8.3
P10.0: MSP1.100 (P10.0/UCB3STE)
P10.1: MSP1.1 (P10.1/UCB3CLK)
P10.2: LV3HP4.2, MSP1.2 (P10.2/UCB3SIMO/UCB3SDA), R10.2, SV7.2
P10.3: LV3HP4.3, MSP1.3 (P10.3UCB3SOMI/UCB3SCL), R9.1, SV7.3
P10.4: MSP1.24 (P10.4/TA3.0/C0.7)
P10.5: MSP1.25 (P10.5/TA3.1/C0.6)
PG: R11.2, U1.3 (PG)
SS: C18.1, U1.1 (SS)
TCK_SWDCLK: J8.4, MSP1.95 (SWCLKTCK)
TDI: J8.8, MSP1.92 (PJ.4/TDI/ADC14CLK)
TDO_SWO: J8.6, MSP1.93 (PJ.5/TDO/SWO)
TMS_SWDIO: J8.2, MSP1.94 (SWDIOTMS)
VCORE: C8.1, C10.1, L1.1, MSP1.12 (VCORE)
VSW: L1.2, MSP1.14 (VSW)
XDSET_VCC: C3.+, C4.1, C7.1, C105.1, IC101.1 (OUT), J8.1, MSP1.13 (DVCC1), MSP1.73 (DVCC2), R1.1, R125.2, R129.2, TP107.1

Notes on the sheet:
LQM21PN4R7NGR
HFX
LFX
Analog
VCC
Digital
DC-DC
5V Header
MSP432P401R Debugger Connector for use with external debug probe Bypass XDS110-ET Remove J101 jumpers to disconnect XDS110
3V3 Header
DEBUG

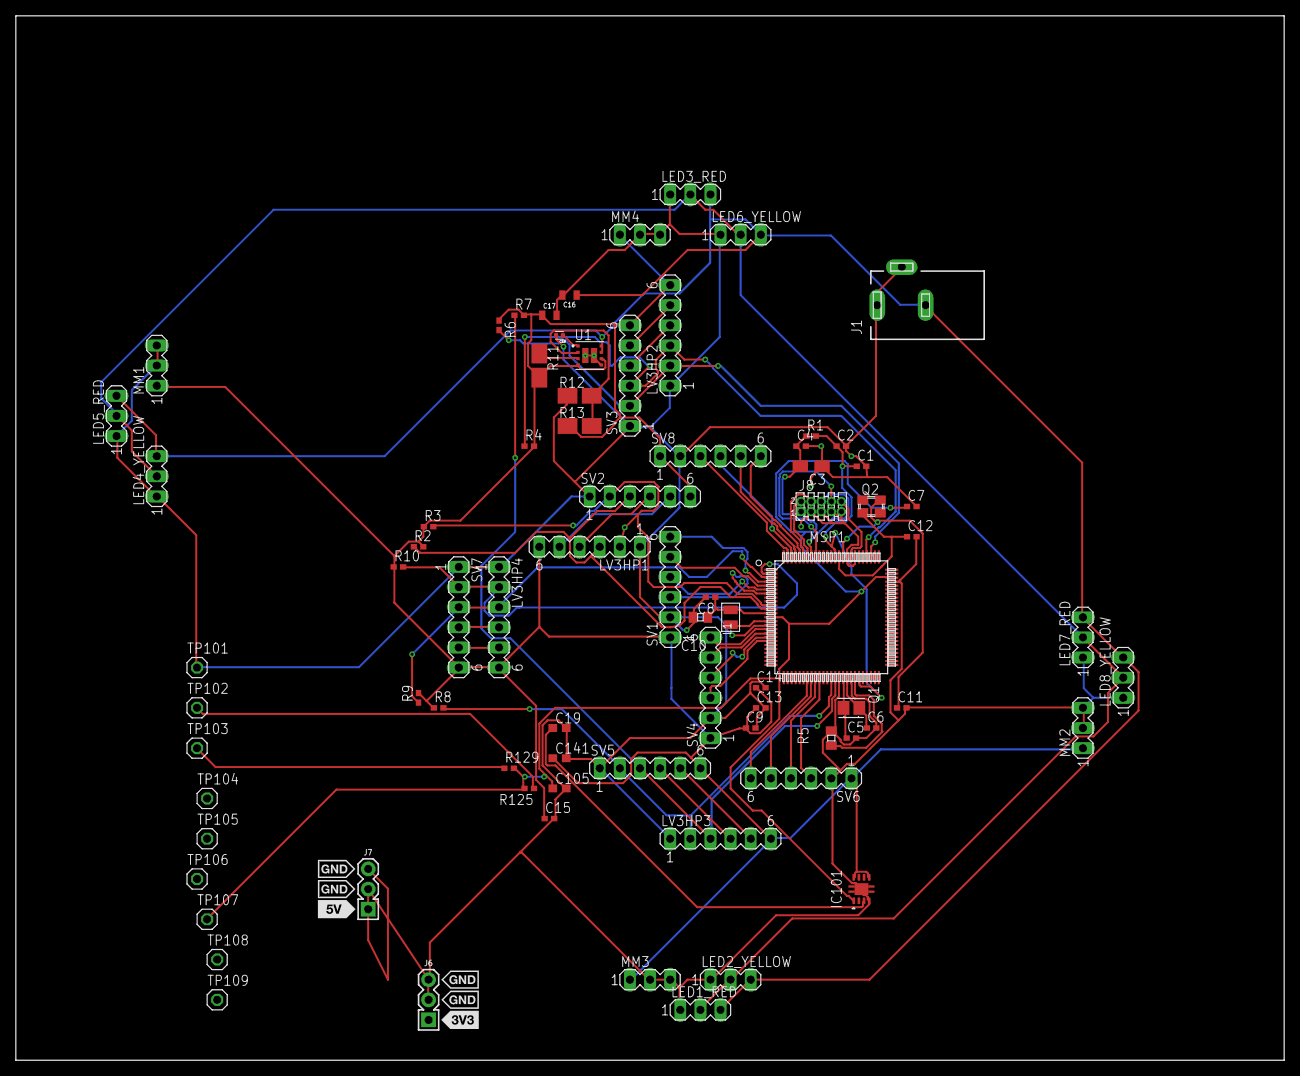
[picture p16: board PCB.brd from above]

Board: 2 copper layers, 160.0 x 131.8 mm, 79 parts (0 on the bottom side), 57 nets.

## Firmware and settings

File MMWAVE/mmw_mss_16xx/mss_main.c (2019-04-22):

/**
 *   @file  mss_main.c
 *
 *   @brief
 *     MSS main implementation of the millimeter wave Demo
 *
 *  \par
 *  NOTE:
 *      (C) Copyright 2016 Texas Instruments, Inc.
 *
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
 *    Redistributions of source code must retain the above copyright
 *    notice, this list of conditions and the following disclaimer.
 *
 *    Redistributions in binary form must reproduce the above copyright
 *    notice, this list of conditions and the following disclaimer in the
 *    documentation and/or other materials provided with the
 *    distribution.
 *
 *    Neither the name of Texas Instruments Incorporated nor the names of
 *    its contributors may be used to endorse or promote products derived
 *    from this software without specific prior written permission.
 *
 *  THIS SOFTWARE IS PROVIDED BY THE COPYRIGHT HOLDERS AND CONTRIBUTORS
 *  "AS IS" AND ANY EXPRESS OR IMPLIED WARRANTIES, INCLUDING, BUT NOT
 *  LIMITED TO, THE IMPLIED WARRANTIES OF MERCHANTABILITY AND FITNESS FOR
 *  A PARTICULAR PURPOSE ARE DISCLAIMED. IN NO EVENT SHALL THE COPYRIGHT
 *  OWNER OR CONTRIBUTORS BE LIABLE FOR ANY DIRECT, INDIRECT, INCIDENTAL,
 *  SPECIAL, EXEMPLARY, OR CONSEQUENTIAL DAMAGES (INCLUDING, BUT NOT
 *  LIMITED TO, PROCUREMENT OF SUBSTITUTE GOODS OR SERVICES; LOSS OF USE,
 *  DATA, OR PROFITS; OR BUSINESS INTERRUPTION) HOWEVER CAUSED AND ON ANY
 *  THEORY OF LIABILITY, WHETHER IN CONTRACT, STRICT LIABILITY, OR TORT
 *  (INCLUDING NEGLIGENCE OR OTHERWISE) ARISING IN ANY WAY OUT OF THE USE
 *  OF THIS SOFTWARE, EVEN IF ADVISED OF THE POSSIBILITY OF SUCH DAMAGE.
 */
/** @mainpage Millimeter Wave (mmw) Demo for XWR16XX
 *
 *  @section intro_sec Introduction
 *
 *  @image html toplevel.png
 *
 *  The millimeter wave demo shows some of the capabilities of the XWR16xx SoC
 *  using the drivers in the mmWave SDK (Software Development Kit).
 *  It allows user to specify the chirping profile and displays the detected
 *  objects and other information in real-time.
 *
 *  Following is a high level description of the features of this demo:
 *  - Be able to specify desired chirping profile through command line interface (CLI) 
 *    on a UART port or through the TI Gallery App - **mmWave Demo Visualizer** - 
 *    that allows user to provide a variety of profile configurations via the UART input port 
 *    and displays the streamed detected output from another UART port in real-time, 
 *    as seen in picture above.
 *  - Some sample profile configurations have been provided in the demo directory that can be
 *    used with CLI directly or via **mmWave Demo Visualizer**:
 *    @verbatim
        mmw/profiles/profile_2d.cfg
        mmw/profiles/profile_2d_srr.cfg
        mmw/profiles/profile_heat_map.cfg
      @endverbatim
 *  - Do 1D, 2D, CFAR and Azimuth processing and stream out velocity
 *    and two spatial coordinates (x,y) of the detected objects in real-time.
 *    The demo can also be configured to do 2D only detection (velocity and x,y coordinates).
 *  - Various display options besides object detection like azimuth heat map and
 *    Doppler-range heat map.
 *  - Illustrates how to configure the various hardware entities (
 *    EDMA, UART) in the AR SoC using the driver software.
 *
 *  @section limit Limitations
 *  
 *  - Because of UART speed limit (< 1 Mbps), the frame time is more restrictive.
 *    For example, for the azimuth and Doppler heat maps for 256 FFT range and
 *    16 point FFT Doppler, it takes about 200 ms to transmit.
 *  - Present implementation in this demo can resolve up to two objects in the azimuth
 *    dimension which have the same range and same velocity. 
 *  - Code will give an error if the requested memory in L3 RAM exceeds its size
 *   (@ref SOC_XWR16XX_DSS_L3RAM_SIZE) due to particular combination  of CLI configuration parameters.
 *  - For most boards, a range bias of few centimeters has been observed. User can estimate
 *    the range bias on their board and correct using the calibration procedure
 *    described in @ref calibration.
 *  
 *  @section tasks System Details
 *  The millimeter wave demo runs on both R4F (MSS) and C674x (DSS).
 *  System startup is described in the following diagram:
 *
 *  @image html system_startup.png "System Startup"
 *
 *
 *  @subsection mss_tasks Software Tasks on MSS
 *    The following (SYSBIOS) tasks are running on MSS:
 *     - @ref MmwDemo_mssInitTask. This task is created and launched by @ref main and is a
 *       one-time initialization  task that performs the following sequence:
 *       -# Initializes drivers (\<driver\>_init).
 *       -# Initializes the MMWave module (MMWave_init)
 *       -# Creates/launches the following tasks (the @ref CLI_task is launched indirectly by 
 *          calling @ref CLI_open).
 *     - @ref MmwDemo_mmWaveCtrlTask. This task is used to provide an execution context 
 *        for the mmWave control, it calls in an endless loop the MMWave_execute API.
 *     - @ref MmwDemo_mssCtrlPathTask. The task is used to process data path events coming
 *       from the @ref CLI_task or start/stop events coming from @ref SOC_XWR16XX_GPIO_1 button on 
 *       EVM. It signals the start/stop completion events back to @ref CLI_task.
 *     - @ref CLI_task. This CLI task takes user commands and posts events to the @ref MmwDemo_mssCtrlPathTask.
 *       In case of start/stop commands, it waits for the completion events from @ref MmwDemo_mssCtrlPathTask and
 *       on success, it toggles the LED @ref SOC_XWR16XX_GPIO_2.
 *     - @ref MmwDemo_mboxReadTask. This task handles mailbox messages received from DSS.
 *
 *  @subsection dss_tasks Software Tasks on DSS
 *
 *  The following four (SYSBIOS) tasks are running on DSS:
 *    - @ref MmwDemo_dssInitTask. This task is created/launched by main (in dss_main.c) and is a
 *      one-time active task that performs the following sequence:
 *      -# Initializes drivers (\<driver\>_init).
 *      -# Initializes the MMWave module (MMWave_init)
 *      -# Creates/launches the other three tasks.
 *    - @ref MmwDemo_mboxReadTask. This task handles mailbox messages received from MSS.
 *    - @ref MmwDemo_dssMMWaveCtrlTask. This task is used to provide an execution
 *      context for the mmWave control, it calls in an endless loop the MMWave_execute API.
 *    - @ref MmwDemo_dssDataPathTask. The task performs in real-time:
 *      - Data path processing chain control and (re-)configuration 
 *        of the hardware entities involved in the processing chain, namely EDMA.
 *      - Data path signal processing such as range, Doppler and azimuth DFT,
 *        object detection, and direction of arrival calculation.
 *      - Transfers detected objects to the HS-RAM shared memory and informs MSS that the data
 *        is ready to be sent out to through the UART output port.
 *        For format of the data on UART output port, see @ref MmwDemo_dssSendProcessOutputToMSS.
 *        The UART transmission is done on MSS.
 *
 *      The task pends on the following events:
 *      - @ref MMWDEMO_CONFIG_EVT. This event is posted by @ref MmwDemo_dssMmwaveConfigCallbackFxn
 *        which in called by MMWAVE_ API triggered when MSS issues MMWAVE_config
 *      - @ref MMWDEMO_BSS_STOP_COMPLETE_EVT. This event is posted by @ref MmwDemo_dssMmwaveEventCallbackFxn when 
 *        the Frame Stop asynchronous event is received. Details as follows:
 *        Initially MSS receives the CLI sensorStop command and issues a stop command to BSS. 
 *        Once BSS fully stops the frame processing, BSS sends a "Frame Stopped Asynchronous event" to MSS. 
 *        MSS then forwards the "Frame Stopped Asynchronous event" to DSS, where
 *        it is handled by @ref MmwDemo_dssMmwaveEventCallbackFxn.
 *        This event causes DSS to go in @ref MmwDemo_DSS_STATE_STOP_PENDING state.
 *        If DSS received the "Frame Stopped Asynchronous event" after the inter-frame processing is completed, 
 *        it will post MMWDEMO_STOP_COMPLETE_EVT. 
 *        Otherwise, it will wait to finish the inter-frame processing before posting MMWDEMO_STOP_COMPLETE_EVT.
 *        See MMWDEMO_STOP_COMPLETE_EVT event below for more details.
 *      - @ref MMWDEMO_FRAMESTART_EVT. This event originates from BSS firmware
 *        and indicates the beginning of the radar frame. It is posted by interrupt
 *        handler function @ref MmwDemo_dssFrameStartIntHandler.
 *      - @ref MMWDEMO_CHIRP_EVT. This event originates from BSS firmware and
 *        indicates that the ADC buffer, (ping or pong) is filled with ADC samples.
 *        It is posted by @ref MmwDemo_dssChirpIntHandler.
 *      - @ref MMWDEMO_START_EVT. This event is posted by @ref MmwDemo_dssMmwaveStartCallbackFxn when 
 *        MMWave_start is called from MSS (on CLI sensorStart 0 command which means starts with
 *        no reconfiguration)
 *      - @ref MMWDEMO_STOP_COMPLETE_EVT. This event is posted either when the MMWDEMO_BSS_STOP_COMPLETE_EVT
 *        is received after the inter-frame processing has ended or when the ongoing active frame finishes sending data over UART.
 *        This event now moves the DSS to MmwDemo_DSS_STATE_STOP state and executes @ref MmwDemo_dssDataPathStop
 *        which further sends @ref MMWDEMO_DSS2MSS_STOPDONE message back to MSS.
 *
 * 
 *  @section datapathtop Data Path
 *  @subsection datapath Data Path - Overall
 *   @image html datapath_overall.png "Top Level Data Path Processing Chain"
 *   \n
 *   \n
 *   @image html datapath_overall_timing.png "Top Level Data Path Timing"
 *    
 *   As seen in the above picture, the data path processing consists of:
 *   - Processing during the chirps as seen in the timing diagram. This
 *     consists of
 *     - 1D (range) FFT processing performed by C674x that takes input from
 *       multiple receive antennas from the ADC buffer for every some number of chirps
 *       (corresponding to the chirping pattern on the transmit antennas), and
 *     - transferring output into the L3 RAM by EDMA. More details
 *       can be seen in @ref data1d
 *   - Processing during the time between the end of chirps until the beginning of the
 *     next chirping period, shown as "Inter Frame Period" in the timing diagram.
 *     This processing consists of:
 *     - 2D (velocity) FFT processing performed by C674x that reads input from 1D output in L3 RAM in a 
 *       transposed manner (using EDMA) and performs
 *       FFT to give a (range,velocity) matrix in the L3 RAM. The processing also includes the CFAR detection in Doppler direction.
 *       More details can be seen in @ref data2d.
 *     - CFAR detection in range direction using mmWave library.
 *     - Peak Grouping if enabled.
 *     - Direction of Arrival (Azimuth) Estimation. More details can be seen at
 *       @ref dataAngElev and @ref dataXYZ
 *  @subsubsection advanced Advanced Frame - Sub Frame Processing
 *   @image html datapath_overall_timing_subframe.png "Top Level Data Path Timing for sub-frames"
 *   \n
 *   \n
 *   In advanced frame mode, sub-frame processing is supported for which the datapath
 *   is essentially same as described in @ref datapath except that there is sub-frame switching
 *   related processing required to prepare for next sub-frame as seen in above diagram. The details
 *   of what is involved in sub-frame switching are described in @ref subFrameSwitching.
 *   The data path for each sub-frame is independent of other sub-frames i.e there is no
 *   combining of information across sub-frames - each sub-frame's results are sent out
 *   to the host after the completion of its data path processing in real-time.
 *
 *  @subsection antConfig Antenna Configurations
 *  The following figure shows antenna layout as seen from the front of
 *  the EVM xWR16xx board alongside the x,y coordinate convention.
 *   @image html antenna_design.png "AWR16xx Antenna layout"
 *
 *   As seen in figures below, the millimeter wave demo supports two antenna configurations:
 *     - Single transmit antenna and four receive antennas.
 *     - Two transmit antennas and four receive antennas. Transmit antennas Tx1 and Tx2
 *       are horizontally spaced at d = 2 Lambda, with their transmissions interleaved in
 *       a frame
 *   @image html antenna_layout_simo.png "Single Tx Antenna Configuration"
 *   \n
 *   @image html antenna_layout_mimo.png "TDM-MIMO Antenna Configuration"
 *   \n
 *
 *    Both configurations allow for azimuth estimation.
 *
 *   @subsection data1d Data Path - 1st Dimension FFT Processing
 *   @image html datapath_1d_tdm_mimo.png "Data Path 1D for TDM-MIMO configuration"
 *   \n
 *
 *   Above picture illustrates 1D chirp processing for the case with one chirp (interrupt) event
 *   for every two chirps and two
 *   transmit antennas, (TDM-MIMO case), as mentioned in @ref antConfig.
 *   There are 4 rx antennas, the samples of which are color-coded and labeled
 *   as 1,2,3,4 with unique coloring for each of chirps that are processed
 *   in ping-pong manner. The 1D FFT chirp processing is triggered by 
 *   hardware chirp event generated when the ADC
 *   has samples to process in the ADC buffer Ping or Pong memories. The hardware event
 *   triggers the registered chirp event interrupt handler function @ref MmwDemo_dssChirpIntHandler,
 *   that in turn posts @ref MMWDEMO_CHIRP_EVT to @ref MmwDemo_dssDataPathTask. The task initiates EDMA
 *   transfer of rx antenna samples in a ping pong manner to parallelize C674x processing
 *   with EDMA data transfer from ADC buffer to L2 memory.
 *   The processing includes FFT calculation using DSP library function with
 *   16-bit input and output precision. Before FFT calculation, a Blackman window
 *   is applied to ADC samples using mmwlib library function. The calculated 1D
 *   FFT samples are EDMA transferred to the radar cube
 *   matrix in L3 memory. One column of the radar cube matrix contains 1D-FFT
 *   samples of chirps corresponding to the two transmit antennas and in this (TDM) case, 
 *   all chirps corresponding to Tx1 are stored consecutively followed by those corresponding
 *   to Tx2. The reason for storing in this way instead of time of arrival order (Tx1,Tx2,Tx1,Tx2..)
 *   is to prevent EDMA jump for 1D output and 2D input from exceeding the EDMA jump limit.
 *   The EDMA jumps (source and destination B/C indices) are 16-bit signed, so when 
 *   number of range bins is 1024 and number of receive antennas is 4, the jump becomes
 *   1024*4*4(bytes/sample)*2(Tx1,Tx2 order) = 32768 which is -32768 as signed 16-bit.
 *   While the jump in 1D output can be overcome by setting the destination address in the compute
 *   loop every chirp output EDMA trigger (which is not too significant burden in cycles),
 *   the 2D cannot be overcome this way without breaking the very purpose of EDMA-CPU parallelism
 *   because the source address would have to be reprogrammed every sample!
 *   The jump is halved (16384) when storing all Tx1 consecutively followed by all Tx2 consecutively.
 *   Picture below illustrates the shape of radar cube matrix
 *   for one Tx antenna configuration, where one column contains 1D FFT samples of one chirp.
 *
 *   @image html datapath_1d_simo_radar_cube.png "Radar cube matrix for single Tx antenna configuration"
 *   \n
 *
 *   The timing diagram of chirp processing is illustrated in figure below.
 *   @image html datapath_1d_timing.png "Data Path 1D timing diagram"
 *   \n
 *
 *  @subsubsection calibDC_Range Antenna coupling signature removal
 *
 *    @image html antenna_coupling_signature_removal.png "Antenna coupling signature removal"
 *
 *  Antenna coupling signature dominates the range bins close to the radar.
 *  These are the bins in the range FFT output located around DC.
 *  This feature is under user control in terms of
 *  enable/disable and start/end range bins through a CLI command called calibDcRangeSig.
 *  During measurement (when the CLI command is issued with feature enabled),
 *  each of the specified range bins for each of the virtual antennas are accumulated
 *  over the specified number of chirps and at the end of the period, the average
 *  is computed for each bin/antenna combination for removal after the measurement
 *  period is over. Note that the number of chirps to average must be power of 2.
 *  It is assumed that no objects are present
 *  in the vicinity of the radar during this measurement period. After measurement
 *  is done, the removal starts for all subsequent frames during which each
 *  of the bin/antenna average estimate is subtracted from the corresponding received samples
 *  in real-time for subsequent processing.
 *
 *  @subsection data2d Data Path - 2nd Dimension FFT Processing
 *   The 2D processing consists of the following steps:
 *   -# For each range bin it performs:
 *     - Static clutter removal if enabled. The mean value of the input samples to the
 *       2D-FFT is subtracted from the samples,
 *     - Windowing - samples are multiplied by a window function,
 *     - 2D-FFT on the samples of 1D-FFT output across chirps (samples are transposed
 *       by the EDMA before 2D FFT can be performed),
 *     - log2 magnitude of the output,
 *     - accumulation across all Rx antennas,
 *     - transfer of accumulated values to detection matrix in L3 using EDMA,
 *     - CFAR pre-detection in Doppler direction and saving of Doppler
 *     indices of detected objects for the final CFAR detection in the range direction.
 *   
 *   -# Final CFAR detection in range direction at Doppler indices at which
 *   objects were detected in previous step
 *   -# Peak grouping. Grouping options are specified by CLI CFAR configuration function and can be
 *     - in both range and Doppler direction,
 *     - only in range,
 *     - only in Doppler direction, or
 *     - none.
 *  \n
 *  The 2D processing is shown in figures below.
 *
 *  @image html datapath_2d_detailed_part1.png "2D-FFT Processing - Calculation of Detection Matrix and CFAR in Doppler direction"
 *  \n
 *  \n
 *  @image html datapath_2d_timing.png "2D-FFT Processing - Calculation of Detection Matrix and CFAR in Doppler direction - timing diagram"
 *  \n
 *  \n
 *  @image html datapath_2d_detailed_part2.png "CFAR in range direction and peak grouping"
 *
 *  @subsubsection peakGrouping Peak grouping
 *  Two peak grouping schemes are implemented:
 *  -# Peak grouping based on peaks of the neighboring bins read from detection
 *  matrix. For each CFAR detected peak, listed in @ref MmwDemo_DSS_DataPathObj::detObj2DRaw,
 *  it checks if the peak is greater than its neighbors. If this is true, the
 *  peak is copied to the output list of detected objects
 *  @ref MmwDemo_DSS_DataPathObj::detObj2D. The neighboring peaks that are used
 *  for checking are taken from the detection matrix @ref MmwDemo_DSS_DataPathObj::detMatrix
 *  and are copied into 3x3 kernel regardless of whether they are CFAR detected or not.
 *  -# Peak grouping based on peaks of neighboring bins that are CFAR detected.
 *  For each detected peak the function checks if the peak is greater than its
 *  neighbors. If this is true, the peak is copied to the output list of
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
int main (void)
{
    Task_Params     taskParams;
    int32_t         errCode;
    SOC_Cfg         socCfg;

    Pinmux_Set_OverrideCtrl(SOC_XWR16XX_PIND13_PADAD, PINMUX_OUTEN_RETAIN_HW_CTRL, PINMUX_INPEN_RETAIN_HW_CTRL);
    Pinmux_Set_FuncSel(SOC_XWR16XX_PIND13_PADAD, SOC_XWR16XX_PIND13_PADAD_SPIA_MOSI);
    Pinmux_Set_OverrideCtrl(SOC_XWR16XX_PINE14_PADAE, PINMUX_OUTEN_RETAIN_HW_CTRL, PINMUX_INPEN_RETAIN_HW_CTRL);
    Pinmux_Set_FuncSel(SOC_XWR16XX_PINE14_PADAE, SOC_XWR16XX_PINE14_PADAE_SPIA_MISO);
    Pinmux_Set_OverrideCtrl(SOC_XWR16XX_PINE13_PADAF, PINMUX_OUTEN_RETAIN_HW_CTRL, PINMUX_INPEN_RETAIN_HW_CTRL);
    Pinmux_Set_FuncSel(SOC_XWR16XX_PINE13_PADAF, SOC_XWR16XX_PINE13_PADAF_SPIA_CLK);
    Pinmux_Set_OverrideCtrl(SOC_XWR16XX_PINC13_PADAG, PINMUX_OUTEN_RETAIN_HW_CTRL, PINMUX_INPEN_RETAIN_HW_CTRL);
    Pinmux_Set_FuncSel(SOC_XWR16XX_PINC13_PADAG, SOC_XWR16XX_PINC13_PADAG_SPIA_CSN);

    SPI_init();


    /* Initialize the ESM: */
    ESM_init(0U); //dont clear errors as TI RTOS does it

    /* Initialize and populate the demo MCB */
    memset ((void*)&gMmwMssMCB, 0, sizeof(MmwDemo_MCB));

    /* Initialize the SOC confiugration: */
    memset ((void *)&socCfg, 0, sizeof(SOC_Cfg));

    /* Populate the SOC configuration: */
    socCfg.clockCfg = SOC_SysClock_INIT;

    /* Initialize the SOC Module: This is done as soon as the application is started
     * to ensure that the MPU is correctly configured. */
    gMmwMssMCB.socHandle   = SOC_init (&socCfg, &errCode);
    if (gMmwMssMCB.socHandle  == NULL)
    {
        System_printf ("Error: SOC Module Initialization failed [Error code %d]\n", errCode);
        return -1;
    }

    /* Initialize the DEMO configuration: */
    gMmwMssMCB.cfg.sysClockFrequency = MSS_SYS_VCLK;
    gMmwMssMCB.cfg.loggingBaudRate   = 921600;
    gMmwMssMCB.cfg.commandBaudRate   = 115200;

    /* Check if the SOC is a secure device */
    if (SOC_isSecureDevice(gMmwMssMCB.socHandle, &errCode))
    {
        /* Disable firewall for JTAG and LOGGER (UART) which is needed by the demo */
        SOC_controlSecureFirewall(gMmwMssMCB.socHandle,
                                  (uint32_t)(SOC_SECURE_FIREWALL_JTAG | SOC_SECURE_FIREWALL_LOGGER),
                                  SOC_SECURE_FIREWALL_DISABLE,
                                  &errCode);
    }

    /* Debug Message: */
    System_printf ("**********************************************\n");
    System_printf ("Debug: Launching the Millimeter Wave Demo\n");
    System_printf ("**********************************************\n");

    /* Initialize the Task Parameters. */
    Task_Params_init(&taskParams);
    taskParams.priority = 3;
    taskParams.stackSize = 2*1024;
    Task_create(MmwDemo_mssInitTask, &taskParams, NULL);

    /* Start BIOS */
    BIOS_start();
    return 0;
}

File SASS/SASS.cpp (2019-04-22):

/*
 * SASS.cpp
 * Created by: Joseph Walters, Trent Sellers 
 */

#ifndef __MSP432P401R__
#define __MSP432P401R__
#endif

/* Standard headers */
#include <stdio.h>

/* XDC module headers */
#include <xdc/runtime/Diags.h>
#include <xdc/runtime/System.h>
#include <xdc/std.h>

/* POSIX thread support */
#include <pthread.h>

/* BIOS module headers */
#include <ti/sysbios/BIOS.h>
#include <ti/sysbios/knl/Task.h>
#include <ti/sysbios/knl/Semaphore.h>

/* Device drivers for GPIO */
#include <ti/devices/msp432p4xx/driverlib/gpio.h>
#include <ti/drivers/GPIO.h>

/* Board-specific headers */
#include <Board.h>

/* SASS-specific headers */
#include <Sources/Control.h>
#include <Sources/Directions.h>
#include <Sources/LLHA/Lights/Lights.h>
#include <Sources/LLHA/Sensors/Lidar.h>
#include <Sources/LLHA/Sensors/Radar.h>
#include <Sources/OC/Classifier.h>
#include <Sources/TLC/Scheduler.h>

// Stack sizes for new tasks
#define STACK_SIZE_SMALL 512
#define STACK_SIZE_MEDIUM 1024
#define STACK_SIZE_LARGE 2048

using namespace sources::llha::sensors;
using namespace sources::llha::lights;
using namespace sources::tlc;

void *sass_init_thread(void *args)
{
    GPIO_setCallback(Board_GPIO_BUTTON0, Classifier::emergency_hwi_callback);
    GPIO_enableInt(Board_GPIO_BUTTON0);
    GPIO_setCallback(Board_GPIO_BUTTON1, Classifier::emergency_hwi_callback);
    GPIO_enableInt(Board_GPIO_BUTTON1);
    GPIO_setCallback(Board_GPIO_MMW1, Classifier::emergency_hwi_callback);
    GPIO_enableInt(Board_GPIO_MMW1);
    GPIO_setCallback(Board_GPIO_MMW2, Classifier::emergency_hwi_callback);
    GPIO_enableInt(Board_GPIO_MMW2);

    pthread_t           scheduler_handle;
    pthread_attr_t      scheduler_attrs;
    struct sched_param  scheduler_priParam;
    int                 thread_error;

    /* Initialize the attributes structure with default values */
    pthread_attr_init(&scheduler_attrs);

    /* Set priority, detach state, and stack size attributes */
    scheduler_priParam.sched_priority = 1;
    thread_error = pthread_attr_setschedparam(&scheduler_attrs, &scheduler_priParam);
    thread_error |= pthread_attr_setdetachstate(&scheduler_attrs, PTHREAD_CREATE_DETACHED);
    thread_error |= pthread_attr_setstacksize(&scheduler_attrs, STACK_SIZE_LARGE);
    if (thread_error) {
        /* failed to set attributes */
        Control::get_instance()->fail_system();
    }

    thread_error = pthread_create(&scheduler_handle, &scheduler_attrs, Scheduler::scheduler_thread, NULL);
    if (thread_error) {
        /* pthread_create() failed */
        Control::get_instance()->fail_system();
    }

    // NOTE: May not need watchman thread
    //    pthread_t           watchman_handle;
    //    pthread_attr_t      watchman_attrs;
    //    struct sched_param  watchman_priParam;
    //
    //    /* Initialize the attributes structure with default values */
    //    pthread_attr_init(&watchman_attrs);
    //
    //    /* Set priority, detach state, and stack size attributes */
    //    watchman_priParam.sched_priority = 1;
    //    thread_error = pthread_attr_setschedparam(&watchman_attrs, &watchman_priParam);
    //    thread_error |= pthread_attr_setdetachstate(&watchman_attrs, PTHREAD_CREATE_DETACHED);
    //    thread_error |= pthread_attr_setstacksize(&watchman_attrs, STACK_SIZE_LARGE);
    //    if (thread_error) {
    //        /* failed to set attributes */
    //        // TODO: Throw exception
    //        while (true) {}
    //    }
    //
    //    thread_error = pthread_create(&watchman_handle, &watchman_attrs, Classifier::watchman_thread, NULL);
    //    if (thread_error) {
    //        /* pthread_create() failed */
    //        // TODO: Throw exception
    //        while (true) {}
    //    }

    pthread_t           classifier_n_handle;
    pthread_attr_t      classifier_n_attrs;
    struct sched_param  classifier_n_priParam;

    /* Initialize the attributes structure with default values */
    pthread_attr_init(&classifier_n_attrs);

    /* Set priority, detach state, and stack size attributes */
    classifier_n_priParam.sched_priority = 1;
    thread_error = pthread_attr_setschedparam(&classifier_n_attrs, &classifier_n_priParam);
    thread_error |= pthread_attr_setdetachstate(&classifier_n_attrs, PTHREAD_CREATE_DETACHED);
    thread_error |= pthread_attr_setstacksize(&classifier_n_attrs, STACK_SIZE_LARGE);
    if (thread_error) {
        /* failed to set attributes */
        Control::get_instance()->fail_system();
    }

    thread_error = pthread_create(&classifier_n_handle, &classifier_n_attrs, Classifier::classifier_thread,
                          (void *)Directions::NORTH);
    if (thread_error) {
        /* pthread_create() failed */
        Control::get_instance()->fail_system();
    }

    pthread_t           classifier_e_handle;
    pthread_attr_t      classifier_e_attrs;
    struct sched_param  classifier_e_priParam;

    /* Initialize the attributes structure with default values */
    pthread_attr_init(&classifier_e_attrs);

    /* Set priority, detach state, and stack size attributes */
    classifier_e_priParam.sched_priority = 1;
    thread_error = pthread_attr_setschedparam(&classifier_e_attrs, &classifier_e_priParam);
    thread_error |= pthread_attr_setdetachstate(&classifier_e_attrs, PTHREAD_CREATE_DETACHED);
    thread_error |= pthread_attr_setstacksize(&classifier_e_attrs, STACK_SIZE_LARGE);
    if (thread_error) {
        /* failed to set attributes */
        Control::get_instance()->fail_system();
    }

    thread_error = pthread_create(&classifier_e_handle, &classifier_e_attrs, Classifier::classifier_thread,
                          (void *)Directions::EAST);
    if (thread_error) {
        /* pthread_create() failed */
        Control::get_instance()->fail_system();
    }

    pthread_exit(NULL);
}
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

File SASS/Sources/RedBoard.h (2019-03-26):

/*
 * RedBoard.h
 * Created by: Joseph Walters, Trent Sellers 
 */

#ifndef REDBOARD_H_
#define REDBOARD_H_

/* Device drivers for GPIO */
#include <ti/devices/msp432p4xx/driverlib/gpio.h>

/* Board-specific headers */
#include <Board.h>

// Slave select lines
#define RADAR_N_SLAVE_SELECT_PORT GPIO_PORT_P1
#define RADAR_E_SLAVE_SELECT_PORT GPIO_PORT_P2
#define RADAR_S_SLAVE_SELECT_PORT
#define RADAR_W_SLAVE_SELECT_PORT

#define RADAR_N_SLAVE_SELECT_PIN GPIO_PIN0
#define RADAR_E_SLAVE_SELECT_PIN GPIO_PIN0
#define RADAR_S_SLAVE_SELECT_PIN
#define RADAR_W_SLAVE_SELECT_PIN

// MISO Lines
#define RADAR_N_MISO_PORT GPIO_PORT_P1
#define RADAR_E_MISO_PORT GPIO_PORT_P2
#define RADAR_S_MISO_PORT
#define RADAR_W_MISO_PORT

#define RADAR_N_MISO_PIN GPIO_PIN1
#define RADAR_E_MISO_PIN GPIO_PIN1
#define RADAR_S_MISO_PIN
#define RADAR_W_MISO_PIN

// MOSI Lines
#define RADAR_N_MOSI_PORT GPIO_PORT_P1
#define RADAR_E_MOSI_PORT GPIO_PORT_P1
#define RADAR_S_MOSI_PORT
#define RADAR_W_MOSI_PORT

#define RADAR_N_MOSI_PIN GPIO_PIN3
#define RADAR_E_MOSI_PIN GPIO_PIN3
#define RADAR_S_MOSI_PIN
#define RADAR_W_MOSI_PIN

// CLK Lines
#define RADAR_N_SLAVE_SELECT_PORT
#define RADAR_E_SLAVE_SELECT_PORT
#define RADAR_S_SLAVE_SELECT_PORT
#define RADAR_W_SLAVE_SELECT_PORT

#define RADAR_N_SLAVE_SELECT_PIN
#define RADAR_E_SLAVE_SELECT_PIN
#define RADAR_S_SLAVE_SELECT_PIN
#define RADAR_W_SLAVE_SELECT_PIN

// SDA Lines
#define LIDAR_N_SDA_PORT GPIO_PORT_P6
#define LIDAR_E_SDA_PORT GPIO_PORT_P6
#define LIDAR_S_SDA_PORT
#define LIDAR_W_SDA_PORT

#define LIDAR_N_SDA_PIN GPIO_PIN4
#define LIDAR_E_SDA_PIN GPIO_PIN4
#define LIDAR_S_SDA_PIN
#define LIDAR_W_SDA_PIN

// SCL Lines
#define LIDAR_N_SCL_PORT GPIO_PORT_P6
#define LIDAR_E_SCL_PORT GPIO_PORT_P6
#define LIDAR_S_SCL_PORT
#define LIDAR_W_SCL_PORT

#define LIDAR_N_SCL_PIN GPIO_PIN5
#define LIDAR_E_SCL_PIN GPIO_PIN5
#define LIDAR_S_SCL_PIN
#define LIDAR_W_SCL_PIN


#define RED_N_PORT GPIO_PORT_P1
#define RED_E_PORT GPIO_PORT_P2
#define RED_S_PORT
#define RED_W_PORT

#define RED_N_PIN GPIO_PIN0
#define RED_E_PIN GPIO_PIN0
#define RED_S_PIN
#define RED_W_PIN


#define YELLOW_N_PORT GPIO_PORT_P2
#define YELLOW_E_PORT GPIO_PORT_P2
#define YELLOW_S_PORT
#define YELLOW_W_PORT

#define YELLOW_N_PIN GPIO_PIN1
#define YELLOW_E_PIN GPIO_PIN2
#define YELLOW_S_PIN
#define YELLOW_W_PIN

#endif // REDBOARD_H_

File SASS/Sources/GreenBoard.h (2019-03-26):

/*
 * GreenBoard.h
 * Created by: Joseph Walters, Trent Sellers 
 */

#ifndef GREENBOARD_H_
#define GREENBOARD_H_

/* Device drivers for GPIO */
#include <ti/devices/msp432p4xx/driverlib/gpio.h>

/* Board-specific headers */
#include <Board.h>

// RADAR assignment
#define RADAR_N Board_SPI4
#define RADAR_E Board_SPI5
#define RADAR_S 100 // NOT IMPLEMENTED
#define RADAR_W 100 // NOT IMPLEMENTED

// LiDAR assignment
#define LIDAR_N Board_I2C1
#define LIDAR_E Board_I2C2
#define LIDAR_S 100 // NOT IMPLEMENTED
#define LIDAR_W 100 // NOT IMPLEMENTED

#define RED_N_PORT GPIO_PORT_P7
#define RED_E_PORT GPIO_PORT_P7
#define RED_S_PORT
#define RED_W_PORT

#define RED_N_PIN GPIO_PIN4
#define RED_E_PIN GPIO_PIN5
#define RED_S_PIN
#define RED_W_PIN

#define YELLOW_N_PORT GPIO_PORT_P7
#define YELLOW_E_PORT GPIO_PORT_P7
#define YELLOW_S_PORT
#define YELLOW_W_PORT

#define YELLOW_N_PIN GPIO_PIN6
#define YELLOW_E_PIN GPIO_PIN7
#define YELLOW_S_PIN
#define YELLOW_W_PIN

#endif // GREENBOARD_H_

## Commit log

2018-11-26 Added First PCB
    [PCB.brd, PCB.sch]
2018-11-28 Updated PCB Schematic
    [PCB.sch]
2018-12-21 Removed PCB schematic from develop branch
    [PCB.sch]
2018-12-21 Added framework for files in CCS
    [SASS.cfg]
2019-01-11 Started fixing C++ files
    [Board.h, Lights.cpp, MSP_EXP432P401R.h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]
2019-01-11 Added board headers
2019-01-11 Added LiDAR headers
2019-01-11 Added SCL naming to LiDAR headers
2019-01-11 Hotfix: SDC/SCL switched by accident
2019-01-11 Removed weird PCB file that got kept by accident on my system
2019-01-15 Added LIDARLite_v3HP Arduino library files as basis for MSP432 adaption
2019-01-15 Commented out Arduino dependencies in LIDARLite_v3HP files
2019-01-15 Added lidarlite stuff
2019-01-17 Resolved issues importing Energia libraries.
    [SASS.cpp]
2019-01-21 Removed LIDAR-Lite libraries and associated files.
2019-01-22 Added Lidar class.
2019-01-22 Refactored Lidar and Radar classes as multitons.
2019-01-22 Updated Lidar and Radar classes to include static methods and members.
2019-01-22 Updated Lidar and Radar classes.
2019-01-22 Added most of lidar code, read/write needs to be implemented
2019-01-22 Made minor changes to Lidar class to allow project to build.
2019-01-22 Made minor naming update to Lidar class.
2019-01-22 Implemented read() and write() methods in Lidar class.
2019-01-23 Implemented get_velocity() method in Lidar class.
2019-01-24 Added basic test_lidar() thread to application.
2019-01-24 Added logger and modified some lidar code
2019-01-25 Refactoring I2C code.
2019-01-25 Modified I2C configuration.
    [SASS.cfg, SASS_pem4f.cfg, build.cfg]
2019-01-29 Reconstructed CCS project to base existing code on latest libraries.
    [SASS.cfg, SASS_pem4f.cfg]
2019-01-31 Better lidar and things
    [SASS.cfg, SASS_pem4f.cfg]
2019-02-01 Modified demo thread for light activation via LiDAR.
2019-02-04 Added mosfetToggleThread.
2019-02-05 Modified mosfetToggleThread.
2019-02-19 Add mmwave demo code with bin files
    [BIOS.obj, arm_IntrinsicsSupport_asm.obj, arm_TaskSupport_asm.obj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]
2019-02-19 Refactored Lidar class to better parallel Radar class.
2019-02-19 Refactored existing demo/test threads and implemented radarTestThread.
2019-02-19 Continued clean up of Lidar class.
2019-02-20 Fixed SPI access issues and added yields to allow for multiple thread execution.
    [MSP_EXP432P401R.c, Radar.cpp, SASS.cpp]
2019-02-21 Remove logger, add docs, optimize Lidar and Radar
2019-02-21 Replaced reference to deprecated POSIX module in SASS.cfg with reference to updated module.
    [SASS.cfg]
2019-02-22 Modified SASS main and Radar class to support SPI software testing.
2019-02-26 Began further implementation of Scheduler and created Scheduler thread.
2019-03-01 Add function to do spi read/write
2019-03-07 Added descriptive header to top of each file, continued clean up of multiple classes, added get_data() method to Radar class, and fixed inheritance of Vehicle class from DetectedObject class.
    [Classifier.cpp, GreenBoard.h, Lidar.cpp]
2019-03-12 Fixed memory leak issues with Classifier thread generation, added to Classifier thread, and added track() method to Classifier class.
    [SASS.cfg, SASS_pem4f.cfg]
2019-03-14 Added to Classifier and Scheduler logic, added timer to Scheduler thread, and removed test print thread.
2019-03-15 Resolved access violation issues, corrected light cues, added delays to Scheduler thread, and prepared Classifier and Scheduler classes for demo.
    [Classifier.cpp, Lidar.cpp, Lights.cpp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]
2019-03-21 Got mmwave to sense distances and velocities accurately
2019-03-22 Added basic triggering of GPIO to process_objects function and included pin mapping.
2019-03-28 Resolved LiDAR access conflict and queue capacity issue; fixed init lighting in Lights class; cleaned up SASS.cpp and Scheduler class.
    [Classifier.cpp, Lights.cpp, SASS.cpp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]
2019-03-28 Improved naming, organization, and performance across classes. Refactored Lidar, Radar, and dependent classes for consistent use of Directions enum.
2019-03-31 Implemented flashing yellow, fixed emergency HWI ISR, and created Control class while adding preliminary SWI functionality.
    [Classifier.cpp, Lidar.cpp, Lights.cpp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]
2019-04-02 Modified GPIO configuration of mmWave pins on PCB to set pins as normal input and raise interrupts on high.
2019-04-02 Fixed system failure interrupt, implemented Timer32 for precise timing in ISRs, and changed MSP type include to use ifndef.
    [Classifier.cpp, Lidar.cpp, Radar.cpp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]
2019-04-04 Modified GPIO configuration and attempted to troubleshoot GPIO HWI issues.
    [Classifier.cpp, MSP_EXP432P401R.c]
2019-04-05 Cleaned up code and refactored Lidar class to allow finer control.
2019-04-05 Added emergency failure interrupts
    [Classifier.cpp, Lidar.cpp, Lights.cpp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]
2019-04-06 mmwave device is stable and works now

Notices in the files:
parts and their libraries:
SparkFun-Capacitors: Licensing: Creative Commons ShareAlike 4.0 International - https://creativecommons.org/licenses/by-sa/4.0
